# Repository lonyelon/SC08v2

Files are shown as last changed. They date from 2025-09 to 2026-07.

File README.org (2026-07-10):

#+title: SC08v2: Simple Computer (8-bits, version 2)

The SC08v2 is a super-simple, *open-hardware 8bit computer* built for retro hardware enthusiasts,
for which a custom default **microcode**, *ISA*, *assembler*, *programming language (based on LISP)*, *compiler* and *operating system* are included.
The design is modular, so any of that can be replaced at any time by the user:

#+BEGIN_EXPORT html
<p align="center">
  <img src="doc/stack.svg" width="500px"/>
</p>
#+END_EXPORT

This repository contains various directories and files that help design, build and test both the computer's hardware and it's software. Those files and directories are the following:

| Directory    | Explanation                                                                             |
|--------------+-----------------------------------------------------------------------------------------|
| =assembler/= | Converts assembly code to binary data.                                                  |
| =microcode/= | Files and scripts that help with designing and building the microcode for the computer. |
| =simulator/= | A complete simulator to test software in.                                               |
| =code/=      | Software for the CPU.                                                                   |
| =code/so=    | Complete OS.                                                                            |
| =doc/=       | Documentation.                                                                          |
| =kicad/=     | KiCAD hardware designs.                                                                 |
| =drawio/=    | DrawIO diagrams.                                                                        |

* Developing software

Check the [[doc/programmers-manual.md][programmers manual]] for a detailed guide on how to make software for the CPU.

* Running software in the CPU

To run software in the *simulated* CPU one has two follow two steps: compilation and execution. Let's run one of the test programs for example:

1. Compile the program by running the compiler: ~python3 ./comp/compiler.py ./asm/test-programs/mult.asm~.
   This will result in a file named =result.bin= being created, which can be either flashed into the CPU's ROM or executed by the simulator.
   Note that the file has a size of exactly 64KB.
2. Run the simulator by entering the =sim= directory and then executing ~cargo run ../result.bin | grep -E '^[0-9]+'~.
   In this case, enter a number (smaller than 255) and press enter.
   Repeat that step and the product of both will be outputted.

This shows that the simulator needs machine code and can not work with assembly code, since it is a one-to-one digital recreation of the real CPU.

* Contributing

Anything can be added to this repo, in whatever programming language you choose to make it, as long as it is a tool or some documentation for the SC08v2.

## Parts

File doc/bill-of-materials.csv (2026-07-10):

Material | Count | Price per unit | Total | Link
6116 | 1
28C64 | 0 | 0
28C512 | 0 | 0
74HC00 | 0 | 0
74HC85 | 0 | 0
74HC86 | 0 | 0
74HC151 | 0 | 0
74HC161 | 3 | 0
74HC245 | 1 | 0
74HC273 | 5 | 0
74HC283 | 0 | 0
100nF C | 9
12uF C | 4
USB poweronly | 1
5.1k Resistor | 1
1nF >=50V C | 1

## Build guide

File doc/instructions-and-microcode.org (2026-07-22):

#+title: SC08v2 default instruction set

The SC08v2 has quite a weird set of instructions by default.
First, we have the [[instructions]] themselves, which tell the CPU what to do.
[[Instruction modifiers]] tell it from where to get the data (or where to store it) after the instruction executed.

For example, ~ADD.num 0x60~ is the function ~ADD~ followed by the modifier ~num~.
It means "add to whatever is on the LDA registry the number =0x60=".

* Intrucctions

The table below explains what every instruction in the CPU does.
Every byte value not in the list is assumed to do nothing, the same as ~NOI.noa~.

|-------+--------------+-------------------------------------------------|
| Name  | Byte         | Value                                           |
|-------+--------------+-------------------------------------------------|
| =NOI= | =00 000 mmm= |                                                 |
| =NAN= | =00 001 mmm= | Bitwise NAND operation between =DTA= and =DTB=. |
| =ADD= | =00 010 mmm= | Add =DTA= and =DTB=.                            |
| =SUB= | =00 011 mmm= | Substract =DTB= from =DTA=.                     |
| =SHL= | =00 100 mmm= | Shift =DTA= left.                               |
| =SHR= | =00 101 mmm= | Shift =DTA= right.                              |
| =EQU= | =00 110 mmm= | Check if =DTA= = =DTB=.                         |
| =GRE= | =00 111 mmm= | Check if =DTA= > =DTB=.                         |
| =LDD= | =01 000 mmm= | Load data into the =DTA= registry.              |
| =STD= | =10 000 mmm= | Store data from the =DTA= registry.             |
| =JUM= | =11 000 mmm= | Conditional jumps. Only jumps if ~DTA != 0xFF~. |
|-------+--------------+-------------------------------------------------|

As we can see, every instruction has two bits for the ID, three for the ALU operation (has to be =000= in non-ALU instructions to allow reading from =DTA=), and three for the modifier.

* Instruction modifiers

|--------------------+--------+---------------------------------------------------------------------------|
| Name [extra bytes] | m-bits | Description                                                               |
|--------------------+--------+---------------------------------------------------------------------------|
| =noa=              |    000 | Do nothing/Pass the value of =DTA=. On ~LDD~ it loads the value of =IFL=. |
| =num #1 [#2]=      |    001 | Hardcoded byte (could be 2 bytes for ROM operations like ~JUM~).          |
| =ram #1=           |    010 | RAM at =#1=.                                                              |
| =rom #1 #2=        |    011 | ROM at =#1 #2=.                                                           |
| =prr=              |    100 | RAM at =RAM[DTA]= (pointer)                                               |
| =ptr #1=           |    101 | RAM at =RAM[#1]= (pointer)                                                |
| =aux=              |    110 | Manage the =AUX= registry.                                                |
| =ios=              |    111 | I/O registries.                                                           |
|--------------------+--------+---------------------------------------------------------------------------|

* Valid instruction-modifier combinations

|-----------------+--------------------------------------------------------------------------------|
| Instruction     | Action                                                                         |
|-----------------+--------------------------------------------------------------------------------|
| ~ALU.noa~       | DTA = DTA                                                                      |
| ~ALU.num #1~    | DTA = DTA <> #1                                                                |
| ~ALU.ram #1~    | DTA = DTA <> RAM[#1]                                                           |
| ~ALU.rom #1 #2~ | DTA = DTA <> ROM[#1][#2]                                                       |
| ~ALU.prr~       | DTA = DTA <> RAM[DTA]                                                          |
| ~ALU.ptr #1~    | DTA = DTA <> RAM[#1]                                                           |
| ~ALU.ios~       | DTA = DTA <> INP                                                               |
|-----------------+--------------------------------------------------------------------------------|
| ~LDD.noa~       | DTA = IFL                                                                      |
| ~LDD.num #1~    | DTA = #1                                                                       |
| ~LDD.ram #1~    | DTA = RAM[#1]                                                                  |
| ~LDD.rom #1 #2~ | DTA = ROM[#1][#2]                                                              |
| ~LDD.prr~       | DTA = RAM[DTA]                                                                 |
| ~LDD.ptr #1~    | DTA = RAM[#1]                                                                  |
| ~LDD.ios~       | DTA = INP                                                                      |
|-----------------+--------------------------------------------------------------------------------|
| ~STD.noa~       | Also called NOI.noa. Do nothing.                                               |
| ~STD.num~       | NOI.noa.                                                                       |
| ~STD.ram #1~    | RAM[#1] = DTA                                                                  |
| ~STD.rom #1 #2~ | ROM[#1][#2] = DTA                                                              |
| ~STD.prr~       | RAM[DTA] = DTA                                                                 |
| ~STD.ptr #1~    | RAM[#1] = DTA                                                                  |
| ~STD.ios~       | OUT = DTA                                                                      |
|-----------------+--------------------------------------------------------------------------------|
| ~JUM.noa~       | Also called NOI.noa. Do nothing.                                               |
| ~JUM.noa~       | PC = #1 #2                                                                     |
| ~JUM.ram #1 #2~ | PC = RAM[#1] RAM[#2]                                                           |
| ~JUM.rom~       | NOI.noa? Only valid if ROM has 2 address bytes, PC S forces SWT and max(PC)=15 |
| ~JUM.prr #1~    | NOI.noa? PC = RAM[DTA] RAM[#1]                                                 |
| ~JUM.ptr #1 #2~ | NOI.noa? PC = RAM[#1] RAM[#2]                                                  |
| ~JUM.ios #1~    | NOI.noa? PC = INP #1                                                           |
|-----------------+--------------------------------------------------------------------------------|

* Full microcode

The full microcode with explanations on what it does can be found under [[../microcode]].

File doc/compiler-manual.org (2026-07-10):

#+title: How does the compiler work

The compiler adds another layer of abstraction on top of the assembler, allowing for the use of a LISP-like programming language (=sclsp=) instead of the assembly language.

The compiler evaluates every expression bottom-up, meaning that, in code like:

#+BEGIN_SRC lsp
(if (> a b) (- a (+ 3 2)))
#+END_SRC

The first element to get evaluated is ~(+ 3 2)~.

Different expressions have different rules.
For example, an `if` expression like ~(if X Y)~ gets translated to:

#+BEGIN_SRC asm
        X               ;; Run X first
        EQU.num 0x00    ;; Invert the value
        JUM.num :endif  ;; Jump if X condition was not met (thats why the value was inverted)
        Y               ;; Execute Y if X was met
:endif  NOI.noa         ;; Placeholder instruction to ensure a destination point for the jump
#+END_SRC

* Common instructions

#+BEGIN_SRC asm
; (= V0 V1)
        LDD.ram V0
        EQU.ram V1

; (= N0 N1)
        LDD.num N0
        EQU.num N1

; (= EXPR0 V1)
        EXPR0
        EQU.ram V1

; (= V0 EXPR0) same as (= EXPR0 V1).
; (> * *) same as (= * *), replace EQU with GRE.
; (<= * *) run (> * *), then
        XOR.num 0xff
; (>= * *)
; (< * *)

; (if N0 EXPR1)
        LDD.num N0
        JUM.num :ifblk
        LDD.num 0xff
        JUM.num :endif
:ifblk  EXPR1
:endif  ...
; (if V0 EXPR1)
        LDD.ram V0
        JUM.num :ifblk
        LDD.num 0xff
        JUM.num :endif
:ifblk  EXPR1
:endif  ...
; (if EXPR0 EXPR1)
        EXPR0
        JUM.num :ifblk
        LDD.num 0xff
        JUM.num :endif
:ifblk  EXPR1
:endif  ...
    
; (if N0 N1 N2)
; (if N0 V1 N2)
; (if N0 EXPR1 N2)
; (if V0 N1 N2)
; (if V0 V1 N2)
; (if V0 EXPR1 N2)
; (if EXPR0 N1 N2)
; (if EXPR0 V1 N2)
; (if EXPR0 EXPR1 N2)
    
; (if N0 N1 V2)
; (if N0 V1 V2)
; (if N0 EXPR1 V2)
; (if V0 N1 V2)
; (if V0 V1 V2)
; (if V0 EXPR1 V2)
; (if EXPR0 N1 V2)
; (if EXPR0 V1 V2)
; (if EXPR0 EXPR1 V2)
    
; (if N0 N1 EXPR2)
; (if N0 V1 EXPR2)
; (if N0 EXPR1 EXPR2)
; (if V0 N1 EXPR2)
; (if V0 V1 EXPR2)
; (if V0 EXPR1 EXPR2)
; (if EXPR0 N1 EXPR2)
; (if EXPR0 V1 EXPR2)
; (if EXPR0 EXPR1 EXPR2)
        EXPR0
        JUM.num :ifblk
        EXPR2
        LDD.num 0xff
        JUM.num :endif
:ifblk  EXPR1
:endif  ...

; (= V0 N1)
        LDD.num N1
        STD.ram V0
; (= V0 V1)
        LDD.ram V0
        ADD.ram V1
        STD.ram V0
; (= V0 EXPR1)
        EXPR1
        ADD.ram V0
        STD.ram V0
    
; (+ V0 N1)
        LDD.num N1
        ADD.ram V0
; (+ V0 V1)
        LDD.ram V1
        ADD.ram V0
; (+ V0 EXPR1)
        EXPR1
        ADD.ram V0
    
; (- V0 N1)
        LDD.num N1
        SUB.ram V0
; (- V0 V1)
        LDD.ram V1
        SUB.ram V0
; (- V0 EXPR1)
        EXPR1
        SUB.ram V0
#+END_SRC

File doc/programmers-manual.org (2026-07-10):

#+title: Assembly programmer's manual

This is the manual for making software for the SC08v2.

* The basics

We use the assembler located at `comp/assembler.py` to convert assembly code into a ROM binary file. The assembly code we use is a custom one made with simplicity in mind, so it should not be really hard to get used to it.

The instructions in the assembly language are made of two elements, the instruction itself and the modifier. For example `LDD.inp` means "load data into the data registry from the input", while `LDD.ram 0x00` means "load data into the data registry from ram at position 0x00". As you can see, arguments need to be passed to instructions sometimes, like the `0x00` before. We will explore the most important instructions and modifiers later, so don't worry too much about this.

To run your software, stored in a `result.bin` file generated after assembling, we can use the program located in `sim/`, which is a full simulator of the CPU written in rust. To run it, use `cargo run <file>`, where the file is out `result.bin`.

* Our first program

Let's build a really basic program for the CPU. In this case, we want to get a number from the user, add one to it and then print it. That program is four bytes in size, and looks like this:

#+BEGIN_SRC asm
        LDD.inp   ; Load the value from the input registry into the RA registry.
        ADD.num 1 ; Add 1 to the RA registry, store it back to RA.
        STD.out   ; Store the value of the RA registry in the output registry.
#+END_SRC

We will ignore the tabs at the beginning of each line for now, we will revisit them later when looking into the `JUM` instruction.

Now, let's make a more complicated program. In this case, we want the user to give two numbers and then add them together. Since we now need two numbers, and we only have one data registry, we need to store the first number to ram to prevent the second one from overwriting it. Then, we add the second number, the one we already have in the data registry, with the first one, placed in the ram at position 0 (0x00).

#+BEGIN_SRC asm
        LDD.inp      ; Get input into RA.
        STD.ram 0x00 ; Store RA into RAM at 0x00.
        LDD.inp      ; Get another input into RA, overwriting the previous one.
        ADD.ram 0x00 ; Add to it the value in RAM at 0x00 (the first input we got).
        STD.out      ; Output the result.
#+END_SRC

Manually managing RAM positions can be a pain, so the assembler allows us to assign names to RAM positions so that we don't lose track of them:

#+BEGIN_SRC asm
#var    first   0x00 ; first = RAM[0x00]
        LDD.inp
        STD.ram first
        LDD.inp
        ADD.ram first
        STD.out
#+END_SRC

And, as we can see, the result is much cleaner. 

** Comments and blank lines

Comments can be added at any place of the program to explain what the software is doing. The following code is the program we already made, but commented so that someone reading it knows what we are doing:

#+BEGIN_SRC asm
#var    first   0x00

        ;; Get the first number.
        LDD.inp
        STD.ram first ; See? we can do this too!
        
        ;; Get the second number.
        LDD.inp
        
        ;; Add them and show the result.
        ADD.ram first
        STD.out

;; Comments can go here too btw, it really doesn't matter.
#+END_SRC

Blank lines can also be really helpful to make the code more readable, so use them freely :).

** The JUM instruction

Another very important instruction is the JUM instruction.
This one allows jumping (surprise?) to a position in ROM.
But things aren't that easy.
The ~JUM~ instruction ONLY jumps if the data registry has a value different than =0=.
So if we want to jump unconditionally, we must run something like:

#+BEGIN_SRC asm
        LDD.num 0xFF   ; Required for the jump to take place. Could be any
                       ; number other than 0.
        JUM.num 0x1234 ; Take note of this.
#+END_SRC

Isn't that =0x1234= weird? This is an 8 bit CPU, but that number is 16 bits in size!
That's because ROM addresses are 16 bits in size to allow 64 KB of storage.
Since the bus (or anything in the CPU, really) can't handle more than 8 bits of data at a given time, the number is split into two and read sequentially.
That results on the ROM looking something like this:

#+BEGIN_SRC asm
0x0003 JUM.num
0x0004 0x12
0x0005 0x34
#+END_SRC

Let's use the JUM instruction to make an infinite loop:

#+BEGIN_SRC asm
        LDD.num 0xFF
        JUM.num 0x0003
#+END_SRC

This is some really awful code, mainly because it is impossible to look at it and know what it is doing.
We see that it is loading 0xff to the data registry (so we can jump) and then jumping to ROM 0x0003.
What is that rom position?
We may not know, and that is why it is awful.
If we count the rom positions, we see that the 0th one is reserved (we won't explain why now),
the first one is used for the ~LDD.num~ instruction, the second one for the number to be loaded (=0xff=), the third one for the jump instruction, the... Eureka!
We are jumping to the third position in the ROM, which is the ~JUM.num~ instruction, so this is an infinite loop that jumps to itself!

See how hard reading that code is?
That's why the assembler allows for naming the positions in the ROM, because in more complicated programs, counting manually to the position we want to jump is impossible, and that position may change in the future if we add instruction in between.
Using position names, the program just becomes:

#+BEGIN_SRC asm
        LDO.num 0xff
:halt   JUM.num :halt
#+END_SRC

Which we can easily understand.
This is the reason we have to always include tabs or spaces before the instructions, in case we want to tag them.

** Comparisons

~JUM~ instructions only become useful once comparisons are understood.
The CPU includes two kinds of comparisons, equality (~EQU~) and greater (~GRE~), but combining both we can get all others.

The comparison instructions take whatever is in the data registry, compare it to a value we give them, and then store the result back into the data registry.
If the comparison was successful, =DTA= is set to =0xFF=, if not, =0x00=.
For example, the following program asks the user for a number, and if the number is 33, then it jumps to another place in the code if it is:

#+BEGIN_SRC asm
        LDD.inp
        EQU.num 33         ; Is the number equal to 33?
        JUM.num :somewhere ; If true, jump to :somewhere
        ...                ; If not, continue here.
#+END_SRC

Let's see what is happening here...
First, the user is being asked for a number, which is getting stored in the data registry.
Then, the number is compared to 33, and if it is equal, =0xff= is written to the data registry and so the ~JUM~ instruction is executed.
If the number is not 33, then =0x00= is stored into the dta registry and the jump instruction is passed.

So that is great, we can do a `== 33` comparison and a `> 33` one, but how about something like `<= 33`? For that one, we need to combine the previous two:

#+BEGIN_SRC asm
        ;; Get the number from the user and store it.
        LDD.inp
        STD.ram 0x00
        
        ;; Check if it is 33, if it is, jump to "true".
        EQU.num 33
        JUM.num :true
        
        ;; Check if the number is greater than 33, if it is, jump to "false".
        LDD.ram 0x00
        GRE.num 33
        JUM.num :false
        
        ;; This gets executed if the first jump executed or if the last one
        ;; didn't.
:true   LDD.num 1
        STD.out
        LDD.num 0xff
        JUM.num :halt

        ;; This gets executed if the first jump didn't get executed but the last
        ;; one did.
:false  LDD.num 0
        STD.out
        LDD.num 0xff
        JUM.num :halt
        
:halt   JUM.num :halt
#+END_SRC

As always, writing this is a pain, but in this case there is no solution for it. Work is being done in a macro system to define a new instruction like `LES.num 33` that gets transformed into the code above at compile-time, but this won't be available soon.

** Pointers

Pointers are a hard-to-understand tool, but a really powerfull one. We will assume going forward the the reader is familiar with how pointers work.

Sometimes the value we have in the data registry is not intended to be a value by itself, but a pointer to a position in ram. For example, in the following program we see how we can access the 16th position in ram by loading the number into the data registry and then resolving the pointer:

#+BEGIN_SRC asm
        LDD.num 0x10 ;; Load 16 into DTA.
        LDD.ptr      ;; Load the 16th position in ram to DTA.
#+END_SRC

Maybe the value we load is by itself a pointer to another place, which can be resolved with ease again:

#+BEGIN_SRC asm
        LDD.num 0x10 ;; Load 16 into DTA.
        LDD.prr      ;; Load the 16th position in ram to DTA.
        LDD.prr      ;; Load the XXth position in ram to DTA.
#+END_SRC

To save instructions, instead of loading data into DTA, we may just use the `prr` (pointer-to-ram) modifier. The following program does the same as the above one, but it saves one instruction:

#+BEGIN_SRC asm
        LDD.prr 0x10 ;; Load RAM at position 0x10, use that as a pointer and resolve it.
        LDD.ptr      ;; Same as before.
#+END_SRC

We could be confused on why to use `ptr` when `prr` exists, but there are cases where it's needed. The one above is one good example of it, but many others can be shown. The next program would be more complicated if we only used `prr` and not `ptr`:

#+BEGIN_SRC asm
        LDD.ram 0x00
        ADD.num 2
        LDD.ptr
        STD.out
#+END_SRC

For a last example, the next program print all the contents in the RAM except for the first position, used for the counter. We leave the explanation as homework for the reader.

#+BEGIN_SRC asm
#var    counter 0x00

        ;; Load and increment the counter.
start   LDD.ram counter
        ADD.num 1
        STD.ram counter
        
        ;; Did we loop back to 0x00? if so, halt.
        EQU.num 0x00
        JUM.num :halt
        
        ;; Show the value in that ram position
        LDD.ptr counter
        STD.out
        
        ;; Go back to the start
        LDD.num 0xff
        JUM.num start
        
        ;; Halt.
halt    JUM.num :halt
#+END_SRC

** Includes

Files can be included into other files, like in C:

#+BEGIN_SRC asm
#inc    firstinclude.asm
#inc    secondinclude.asm
#+END_SRC

Beware of include loops! The assembler doen't check for them yet!

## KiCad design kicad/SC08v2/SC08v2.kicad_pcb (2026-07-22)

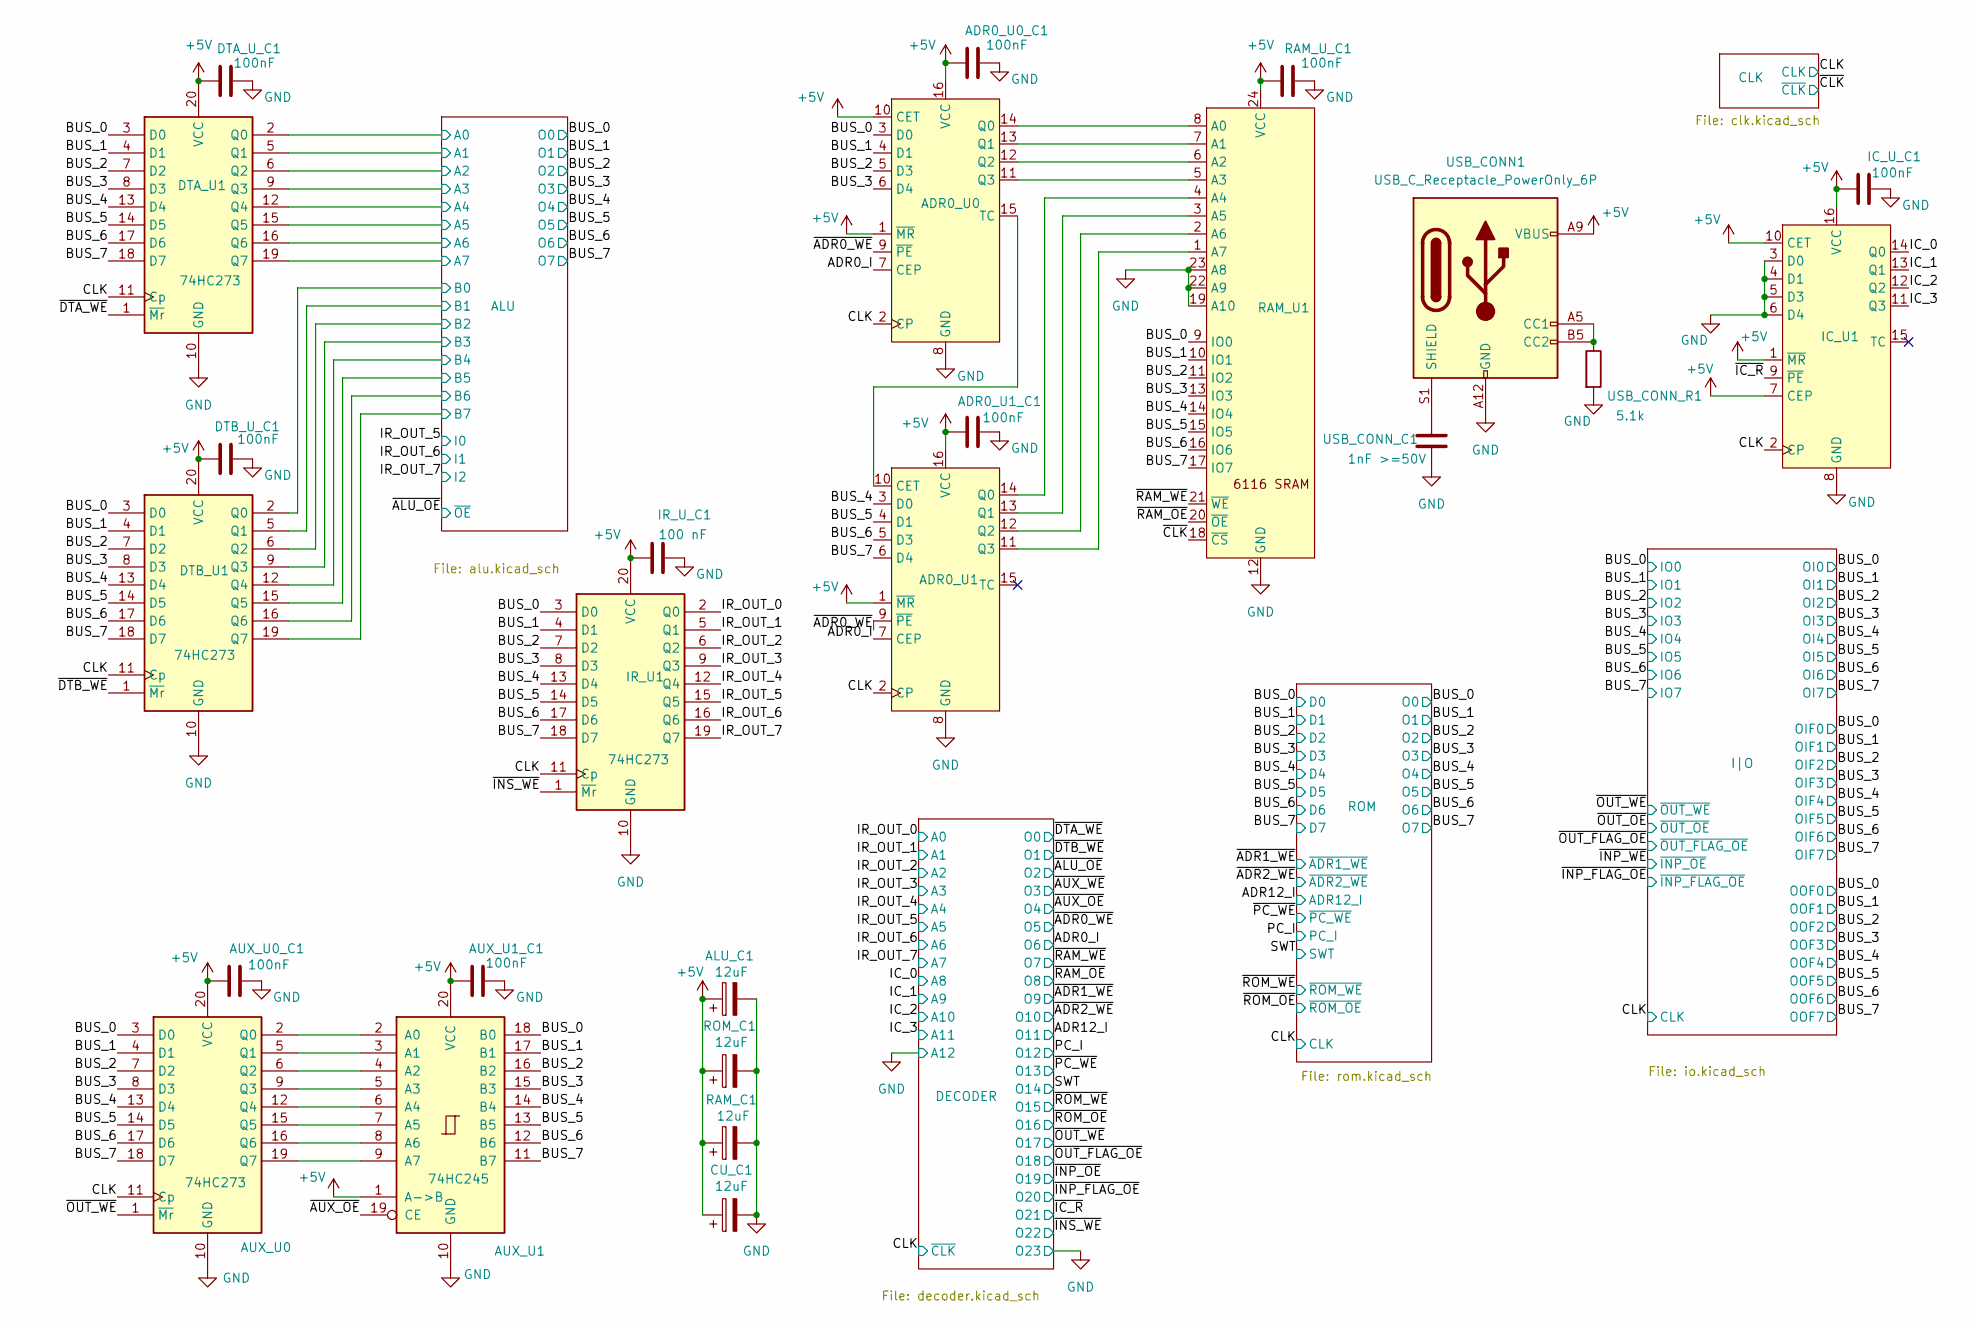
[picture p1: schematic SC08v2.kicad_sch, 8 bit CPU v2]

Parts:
ADR0_U0, ADR0_U1: DIP-16_W7.62mm
ADR0_U0_C1, ADR0_U1_C1: 100nF; C_Disc_D3.0mm_W1.6mm_P2.50mm
ALU_C1: 12uF; C_Radial_D5.0mm_H5.0mm_P2.00mm
AUX_U0: 74HC273; DIP-20_W7.62mm
AUX_U0_C1, AUX_U1_C1: 100nF; C_Disc_D3.0mm_W1.6mm_P2.50mm
AUX_U1: 74HC245; DIP-20_W7.62mm
CU_C1: 12uF; C_Radial_D5.0mm_H5.0mm_P2.00mm
DTA_U1: 74HC273; DIP-20_W7.62mm
DTA_U_C1: 100nF; C_Disc_D3.0mm_W1.6mm_P2.50mm
DTB_U1: 74HC273; DIP-20_W7.62mm
DTB_U_C1: 100nF; C_Disc_D3.0mm_W1.6mm_P2.50mm
IC_U1: DIP-16_W7.62mm
IC_U_C1: 100nF; C_Disc_D3.0mm_W1.6mm_P2.50mm
IR_U1: 74HC273; DIP-20_W7.62mm
IR_U_C1: 100 nF; C_Disc_D3.0mm_W1.6mm_P2.50mm
RAM_C1: 12uF; C_Radial_D5.0mm_H5.0mm_P2.00mm
RAM_U1: DIP-24_18.0mmx34.29mm_W15.24mm
RAM_U_C1: 100nF; C_Disc_D3.0mm_W1.6mm_P2.50mm
ROM_C1: 12uF; C_Radial_D5.0mm_H5.0mm_P2.00mm
USB_CONN1: USB_C_Receptacle_PowerOnly_6P; USB_C_Receptacle_GCT_USB4125-xx-x-0190_6P_TopMnt_Horizontal
USB_CONN_C1: 1nF >=50V; C_Disc_D3.0mm_W1.6mm_P2.50mm
USB_CONN_R1: 5.1k; R_Axial_DIN0204_L3.6mm_D1.6mm_P5.08mm_Horizontal

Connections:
+5V: ADR0_U0.1 (~MR), ADR0_U0.10 (CET), ADR0_U0.16 (VCC), ADR0_U0_C1.1, ADR0_U1.1 (~MR), ADR0_U1.16 (VCC), ADR0_U1_C1.1, ALU_C1.1, AUX_U0.20 (VCC), AUX_U0_C1.1, AUX_U1.1 (A->B), AUX_U1.20 (VCC), AUX_U1_C1.1, CU_C1.1, DTA_U1.20 (VCC), DTA_U_C1.1, DTB_U1.20 (VCC), DTB_U_C1.1, IC_U1.1 (~MR), IC_U1.7 (CEP), IC_U1.10 (CET), IC_U1.16 (VCC), IC_U_C1.1, IR_U1.20 (VCC), IR_U_C1.1, RAM_C1.1, RAM_U1.24 (VCC), RAM_U_C1.1, ROM_C1.1, USB_CONN1.A9 (VBUS), USB_CONN1.B9 (VBUS); also elsewhere on the board
/ADR0_I: ADR0_U0.7 (CEP), ADR0_U1.7 (CEP); also elsewhere on the board
/ALU/A0: DTA_U1.2 (Q0); also elsewhere on the board
/ALU/A1: DTA_U1.5 (Q1); also elsewhere on the board
/ALU/A2: DTA_U1.6 (Q2); also elsewhere on the board
/ALU/A3: DTA_U1.9 (Q3); also elsewhere on the board
/ALU/A4: DTA_U1.12 (Q4); also elsewhere on the board
/ALU/A5: DTA_U1.15 (Q5); also elsewhere on the board
/ALU/A6: DTA_U1.16 (Q6); also elsewhere on the board
/ALU/A7: DTA_U1.19 (Q7); also elsewhere on the board
/ALU/B0: DTB_U1.2 (Q0); also elsewhere on the board
/ALU/B1: DTB_U1.5 (Q1); also elsewhere on the board
/ALU/B2: DTB_U1.6 (Q2); also elsewhere on the board
/ALU/B3: DTB_U1.9 (Q3); also elsewhere on the board
/ALU/B4: DTB_U1.12 (Q4); also elsewhere on the board
/ALU/B5: DTB_U1.15 (Q5); also elsewhere on the board
/ALU/B6: DTB_U1.16 (Q6); also elsewhere on the board
/ALU/B7: DTB_U1.19 (Q7); also elsewhere on the board
/BUS_0: ADR0_U0.3 (D0), AUX_U0.3 (D0), AUX_U1.18 (B0), DTA_U1.3 (D0), DTB_U1.3 (D0), IR_U1.3 (D0), RAM_U1.9 (IO0); also elsewhere on the board
/BUS_1: ADR0_U0.4 (D1), AUX_U0.4 (D1), AUX_U1.17 (B1), DTA_U1.4 (D1), DTB_U1.4 (D1), IR_U1.4 (D1), RAM_U1.10 (IO1); also elsewhere on the board
/BUS_2: ADR0_U0.5 (D3), AUX_U0.7 (D2), AUX_U1.16 (B2), DTA_U1.7 (D2), DTB_U1.7 (D2), IR_U1.7 (D2), RAM_U1.11 (IO2); also elsewhere on the board
/BUS_3: ADR0_U0.6 (D4), AUX_U0.8 (D3), AUX_U1.15 (B3), DTA_U1.8 (D3), DTB_U1.8 (D3), IR_U1.8 (D3), RAM_U1.13 (IO3); also elsewhere on the board
/BUS_4: ADR0_U1.3 (D0), AUX_U0.13 (D4), AUX_U1.14 (B4), DTA_U1.13 (D4), DTB_U1.13 (D4), IR_U1.13 (D4), RAM_U1.14 (IO4); also elsewhere on the board
/BUS_5: ADR0_U1.4 (D1), AUX_U0.14 (D5), AUX_U1.13 (B5), DTA_U1.14 (D5), DTB_U1.14 (D5), IR_U1.14 (D5), RAM_U1.15 (IO5); also elsewhere on the board
/BUS_6: ADR0_U1.5 (D3), AUX_U0.17 (D6), AUX_U1.12 (B6), DTA_U1.17 (D6), DTB_U1.17 (D6), IR_U1.17 (D6), RAM_U1.16 (IO6); also elsewhere on the board
/BUS_7: ADR0_U1.6 (D4), AUX_U0.18 (D7), AUX_U1.11 (B7), DTA_U1.18 (D7), DTB_U1.18 (D7), IR_U1.18 (D7), RAM_U1.17 (IO7); also elsewhere on the board
/CLK: ADR0_U0.2 (CP), ADR0_U1.2 (CP), AUX_U0.11 (Cp), DTA_U1.11 (Cp), DTB_U1.11 (Cp), IC_U1.2 (CP), IR_U1.11 (Cp); also elsewhere on the board
/IC_0: IC_U1.14 (Q0); also elsewhere on the board
/IC_1: IC_U1.13 (Q1); also elsewhere on the board
/IC_2: IC_U1.12 (Q2); also elsewhere on the board
/IC_3: IC_U1.11 (Q3); also elsewhere on the board
/IR_OUT_0: IR_U1.2 (Q0); also elsewhere on the board
/IR_OUT_1: IR_U1.5 (Q1); also elsewhere on the board
/IR_OUT_2: IR_U1.6 (Q2); also elsewhere on the board
/IR_OUT_3: IR_U1.9 (Q3); also elsewhere on the board
/IR_OUT_4: IR_U1.12 (Q4); also elsewhere on the board
/IR_OUT_5: IR_U1.15 (Q5); also elsewhere on the board
/IR_OUT_6: IR_U1.16 (Q6); also elsewhere on the board
/IR_OUT_7: IR_U1.19 (Q7); also elsewhere on the board
/~ADR0_WE: ADR0_U0.9 (~PE), ADR0_U1.9 (~PE); also elsewhere on the board
/~AUX_OE: AUX_U1.19 (CE); also elsewhere on the board
/~CLK: RAM_U1.18 (~CS); also elsewhere on the board
/~DTA_WE: DTA_U1.1 (~Mr); also elsewhere on the board
/~DTB_WE: DTB_U1.1 (~Mr); also elsewhere on the board
/~IC_R: IC_U1.9 (~PE); also elsewhere on the board
/~INS_WE: IR_U1.1 (~Mr); also elsewhere on the board
/~OUT_WE: AUX_U0.1 (~Mr); also elsewhere on the board
/~RAM_OE: RAM_U1.20 (~OE); also elsewhere on the board
/~RAM_WE: RAM_U1.21 (~WE); also elsewhere on the board
GND: ADR0_U0.8 (GND), ADR0_U0_C1.2, ADR0_U1.8 (GND), ADR0_U1_C1.2, ALU_C1.2, AUX_U0.10 (GND), AUX_U0_C1.2, AUX_U1.10 (GND), AUX_U1_C1.2, CU_C1.2, DTA_U1.10 (GND), DTA_U_C1.2, DTB_U1.10 (GND), DTB_U_C1.2, IC_U1.3 (D0), IC_U1.4 (D1), IC_U1.5 (D3), IC_U1.6 (D4), IC_U1.8 (GND), IC_U_C1.2, IR_U1.10 (GND), IR_U_C1.2, RAM_C1.2, RAM_U1.12 (GND), RAM_U1.19 (A10), RAM_U1.22 (A9), RAM_U1.23 (A8), RAM_U_C1.2, ROM_C1.2, USB_CONN1.A12 (GND), USB_CONN1.B12 (GND), USB_CONN_C1.2, USB_CONN_R1.2; also elsewhere on the board
unnamed: ADR0_U0.14 (Q0), RAM_U1.8 (A0)
unnamed: ADR0_U0.13 (Q1), RAM_U1.7 (A1)
unnamed: ADR0_U0.12 (Q2), RAM_U1.6 (A2)
unnamed: ADR0_U0.11 (Q3), RAM_U1.5 (A3)
unnamed: ADR0_U0.15 (TC), ADR0_U1.10 (CET)
unnamed: ADR0_U1.14 (Q0), RAM_U1.4 (A4)
unnamed: ADR0_U1.13 (Q1), RAM_U1.3 (A5)
unnamed: ADR0_U1.12 (Q2), RAM_U1.2 (A6)
unnamed: ADR0_U1.11 (Q3), RAM_U1.1 (A7)
unnamed: AUX_U0.2 (Q0), AUX_U1.2 (A0)
unnamed: AUX_U0.5 (Q1), AUX_U1.3 (A1)
unnamed: AUX_U0.6 (Q2), AUX_U1.4 (A2)
unnamed: AUX_U0.9 (Q3), AUX_U1.5 (A3)
unnamed: AUX_U0.12 (Q4), AUX_U1.6 (A4)
unnamed: AUX_U0.15 (Q5), AUX_U1.7 (A5)
unnamed: AUX_U0.16 (Q6), AUX_U1.8 (A6)
unnamed: AUX_U0.19 (Q7), AUX_U1.9 (A7)
unnamed: USB_CONN1.A5 (CC1), USB_CONN1.B5 (CC2), USB_CONN_R1.1
unnamed: USB_CONN1.S1 (SHIELD), USB_CONN_C1.1

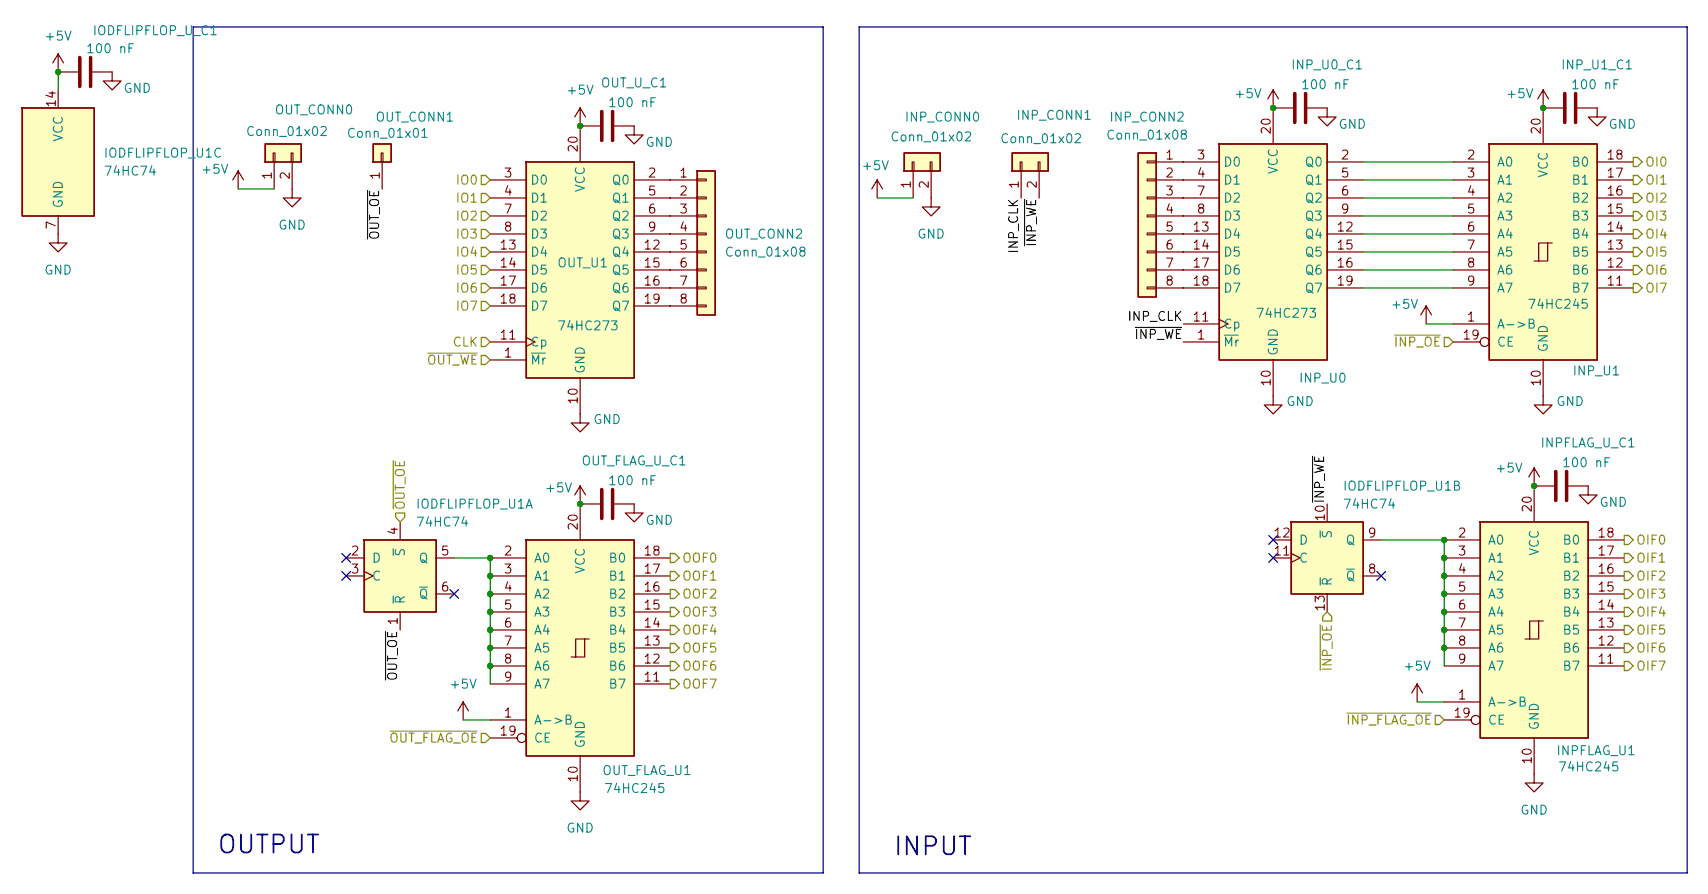
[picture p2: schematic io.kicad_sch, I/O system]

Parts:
INPFLAG_U1: 74HC245; DIP-20_W7.62mm
INPFLAG_U_C1: 100 nF; C_Disc_D3.0mm_W1.6mm_P2.50mm
INP_CONN0, INP_CONN1: Conn_01x02; PinHeader_1x02_P2.54mm_Vertical
INP_CONN2: Conn_01x08; PinHeader_1x08_P2.54mm_Vertical
INP_U0: 74HC273; DIP-20_W7.62mm
INP_U0_C1, INP_U1_C1: 100 nF; C_Disc_D3.0mm_W1.6mm_P2.50mm
INP_U1: 74HC245; DIP-20_W7.62mm
IODFLIPFLOP_U1: 74HC74; DIP-14_W7.62mm
IODFLIPFLOP_U_C1: 100 nF; C_Disc_D3.0mm_W1.6mm_P2.50mm
OUT_CONN0: Conn_01x02; PinHeader_1x02_P2.54mm_Vertical
OUT_CONN1: Conn_01x01; PinHeader_1x01_P2.54mm_Vertical
OUT_CONN2: Conn_01x08; PinHeader_1x08_P2.54mm_Vertical
OUT_FLAG_U1: 74HC245; DIP-20_W7.62mm
OUT_FLAG_U_C1: 100 nF; C_Disc_D3.0mm_W1.6mm_P2.50mm
OUT_U1: 74HC273; DIP-20_W7.62mm
OUT_U_C1: 100 nF; C_Disc_D3.0mm_W1.6mm_P2.50mm

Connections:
+5V: INPFLAG_U1.1 (A->B), INPFLAG_U1.20 (VCC), INPFLAG_U_C1.1, INP_CONN0.1, INP_U0.20 (VCC), INP_U0_C1.1, INP_U1.1 (A->B), INP_U1.20 (VCC), INP_U1_C1.1, IODFLIPFLOP_U1.14 (VCC), IODFLIPFLOP_U_C1.1, OUT_CONN0.1, OUT_FLAG_U1.1 (A->B), OUT_FLAG_U1.20 (VCC), OUT_FLAG_U_C1.1, OUT_U1.20 (VCC), OUT_U_C1.1; also elsewhere on the board
/BUS_0: INPFLAG_U1.18 (B0), INP_U1.18 (B0), OUT_FLAG_U1.18 (B0), OUT_U1.3 (D0); also elsewhere on the board
/BUS_1: INPFLAG_U1.17 (B1), INP_U1.17 (B1), OUT_FLAG_U1.17 (B1), OUT_U1.4 (D1); also elsewhere on the board
/BUS_2: INPFLAG_U1.16 (B2), INP_U1.16 (B2), OUT_FLAG_U1.16 (B2), OUT_U1.7 (D2); also elsewhere on the board
/BUS_3: INPFLAG_U1.15 (B3), INP_U1.15 (B3), OUT_FLAG_U1.15 (B3), OUT_U1.8 (D3); also elsewhere on the board
/BUS_4: INPFLAG_U1.14 (B4), INP_U1.14 (B4), OUT_FLAG_U1.14 (B4), OUT_U1.13 (D4); also elsewhere on the board
/BUS_5: INPFLAG_U1.13 (B5), INP_U1.13 (B5), OUT_FLAG_U1.13 (B5), OUT_U1.14 (D5); also elsewhere on the board
/BUS_6: INPFLAG_U1.12 (B6), INP_U1.12 (B6), OUT_FLAG_U1.12 (B6), OUT_U1.17 (D6); also elsewhere on the board
/BUS_7: INPFLAG_U1.11 (B7), INP_U1.11 (B7), OUT_FLAG_U1.11 (B7), OUT_U1.18 (D7); also elsewhere on the board
/CLK: OUT_U1.11 (Cp); also elsewhere on the board
/I|O/INP_CLK: INP_CONN1.1, INP_U0.11 (Cp)
/I|O/~INP_WE: INP_CONN1.2, INP_U0.1 (~Mr), IODFLIPFLOP_U1.10 (~S)
/~INP_FLAG_OE: INPFLAG_U1.19 (CE); also elsewhere on the board
/~INP_WE: INP_U1.19 (CE), IODFLIPFLOP_U1.13 (~R)
/~OUT_FLAG_OE: OUT_FLAG_U1.19 (CE); also elsewhere on the board
/~OUT_OE: IODFLIPFLOP_U1.1 (~R), IODFLIPFLOP_U1.4 (~S), OUT_CONN1.1 (Pin_1_1)
/~OUT_WE: OUT_U1.1 (~Mr); also elsewhere on the board
GND: INPFLAG_U1.10 (GND), INPFLAG_U_C1.2, INP_CONN0.2, INP_U0.10 (GND), INP_U0_C1.2, INP_U1.10 (GND), INP_U1_C1.2, IODFLIPFLOP_U1.7 (GND), IODFLIPFLOP_U_C1.2, OUT_CONN0.2, OUT_FLAG_U1.10 (GND), OUT_FLAG_U_C1.2, OUT_U1.10 (GND), OUT_U_C1.2; also elsewhere on the board
unnamed: INPFLAG_U1.2 (A0), INPFLAG_U1.3 (A1), INPFLAG_U1.4 (A2), INPFLAG_U1.5 (A3), INPFLAG_U1.6 (A4), INPFLAG_U1.7 (A5), INPFLAG_U1.8 (A6), INPFLAG_U1.9 (A7), IODFLIPFLOP_U1.9 (Q)
unnamed: INP_CONN2.1, INP_U0.3 (D0)
unnamed: INP_CONN2.2, INP_U0.4 (D1)
unnamed: INP_CONN2.3, INP_U0.7 (D2)
unnamed: INP_CONN2.4, INP_U0.8 (D3)
unnamed: INP_CONN2.5, INP_U0.13 (D4)
unnamed: INP_CONN2.6, INP_U0.14 (D5)
unnamed: INP_CONN2.7, INP_U0.17 (D6)
unnamed: INP_CONN2.8, INP_U0.18 (D7)
unnamed: INP_U0.2 (Q0), INP_U1.2 (A0)
unnamed: INP_U0.5 (Q1), INP_U1.3 (A1)
unnamed: INP_U0.6 (Q2), INP_U1.4 (A2)
unnamed: INP_U0.9 (Q3), INP_U1.5 (A3)
unnamed: INP_U0.12 (Q4), INP_U1.6 (A4)
unnamed: INP_U0.15 (Q5), INP_U1.7 (A5)
unnamed: INP_U0.16 (Q6), INP_U1.8 (A6)
unnamed: INP_U0.19 (Q7), INP_U1.9 (A7)
unnamed: IODFLIPFLOP_U1.5 (Q), OUT_FLAG_U1.2 (A0), OUT_FLAG_U1.3 (A1), OUT_FLAG_U1.4 (A2), OUT_FLAG_U1.5 (A3), OUT_FLAG_U1.6 (A4), OUT_FLAG_U1.7 (A5), OUT_FLAG_U1.8 (A6), OUT_FLAG_U1.9 (A7)
unnamed: OUT_CONN2.1, OUT_U1.2 (Q0)
unnamed: OUT_CONN2.2, OUT_U1.5 (Q1)
unnamed: OUT_CONN2.3, OUT_U1.6 (Q2)
unnamed: OUT_CONN2.4, OUT_U1.9 (Q3)
unnamed: OUT_CONN2.5, OUT_U1.12 (Q4)
unnamed: OUT_CONN2.6, OUT_U1.15 (Q5)
unnamed: OUT_CONN2.7, OUT_U1.16 (Q6)
unnamed: OUT_CONN2.8, OUT_U1.19 (Q7)

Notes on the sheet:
INPUT
OUTPUT

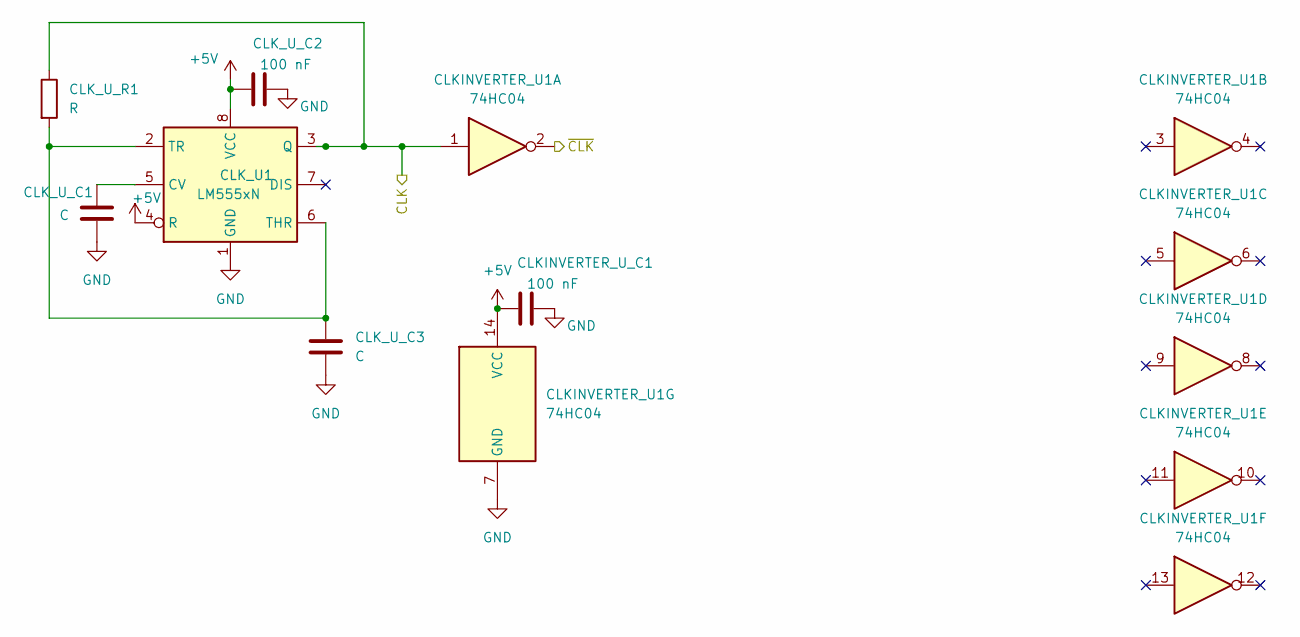
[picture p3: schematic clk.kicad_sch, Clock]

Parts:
CLKINVERTER_U1: 74HC04; DIP-14_W7.62mm
CLKINVERTER_U_C1: 100 nF; C_Disc_D3.0mm_W1.6mm_P2.50mm
CLK_U1: LM555xN; DIP-8_W7.62mm
CLK_U_C1, CLK_U_C3: C; C_Disc_D3.0mm_W1.6mm_P2.50mm
CLK_U_C2: 100 nF; C_Disc_D3.0mm_W1.6mm_P2.50mm
CLK_U_R1: R; R_Axial_DIN0204_L3.6mm_D1.6mm_P5.08mm_Horizontal

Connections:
+5V: CLKINVERTER_U1.14 (VCC), CLKINVERTER_U_C1.1, CLK_U1.4 (R), CLK_U1.8 (VCC), CLK_U_C2.1; also elsewhere on the board
/CLK: CLKINVERTER_U1.1, CLK_U1.3 (Q), CLK_U_R1.1; also elsewhere on the board
/~CLK: CLKINVERTER_U1.2; also elsewhere on the board
GND: CLKINVERTER_U1.7 (GND), CLKINVERTER_U_C1.2, CLK_U1.1 (GND), CLK_U_C1.2, CLK_U_C2.2, CLK_U_C3.2; also elsewhere on the board
unnamed: CLK_U1.5 (CV), CLK_U_C1.1
unnamed: CLK_U1.2 (TR), CLK_U1.6 (THR), CLK_U_C3.1, CLK_U_R1.2

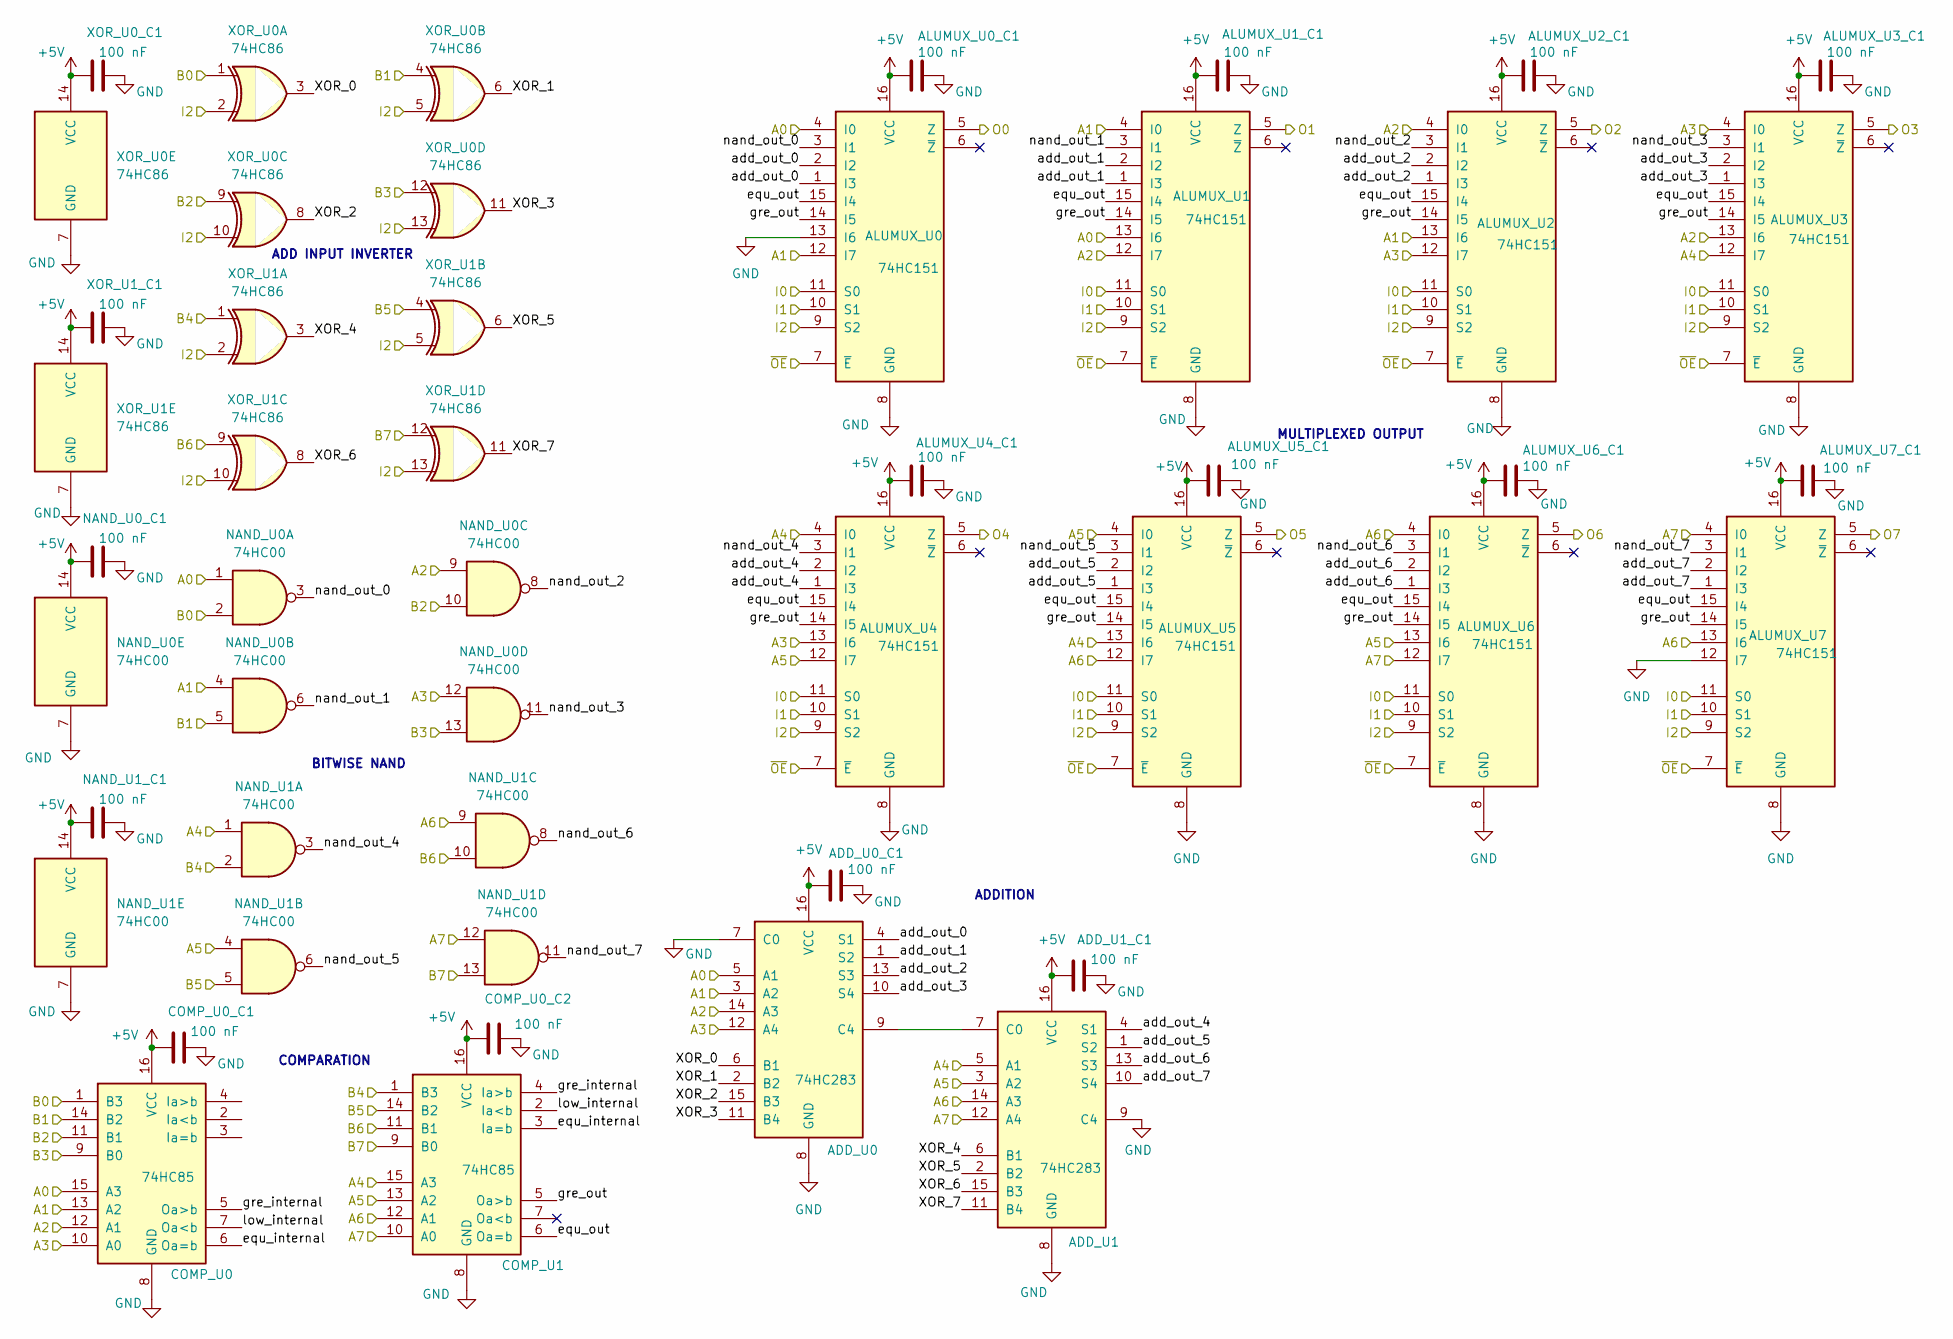
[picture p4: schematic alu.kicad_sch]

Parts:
ADD_U0, ADD_U1: 74HC283; DIP-16_W7.62mm
ADD_U0_C1, ADD_U1_C1: 100 nF; C_Disc_D3.0mm_W1.6mm_P2.50mm
ALUMUX_U0, ALUMUX_U1, ALUMUX_U2, ALUMUX_U3, ALUMUX_U4, ALUMUX_U5, ALUMUX_U6, ALUMUX_U7: 74HC151; DIP-16_W7.62mm
ALUMUX_U0_C1, ALUMUX_U1_C1, ALUMUX_U2_C1, ALUMUX_U3_C1, ALUMUX_U4_C1, ALUMUX_U5_C1, ALUMUX_U6_C1, ALUMUX_U7_C1: 100 nF; C_Disc_D3.0mm_W1.6mm_P2.50mm
COMP_U0, COMP_U1: 74HC85; DIP-16_W7.62mm
COMP_U0_C1, COMP_U0_C2: 100 nF; C_Disc_D3.0mm_W1.6mm_P2.50mm
NAND_U0, NAND_U1: 74HC00; DIP-14_W7.62mm
NAND_U0_C1, NAND_U1_C1: 100 nF; C_Disc_D3.0mm_W1.6mm_P2.50mm
XOR_U0, XOR_U1: 74HC86; DIP-14_W7.62mm
XOR_U0_C1, XOR_U1_C1: 100 nF; C_Disc_D3.0mm_W1.6mm_P2.50mm

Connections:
+5V: ADD_U0.16 (VCC), ADD_U0_C1.1, ADD_U1.16 (VCC), ADD_U1_C1.1, ALUMUX_U0.16 (VCC), ALUMUX_U0_C1.1, ALUMUX_U1.16 (VCC), ALUMUX_U1_C1.1, ALUMUX_U2.16 (VCC), ALUMUX_U2_C1.1, ALUMUX_U3.16 (VCC), ALUMUX_U3_C1.1, ALUMUX_U4.16 (VCC), ALUMUX_U4_C1.1, ALUMUX_U5.16 (VCC), ALUMUX_U5_C1.1, ALUMUX_U6.16 (VCC), ALUMUX_U6_C1.1, ALUMUX_U7.16 (VCC), ALUMUX_U7_C1.1, COMP_U0.16 (VCC), COMP_U0_C1.1, COMP_U0_C2.1, COMP_U1.16 (VCC), NAND_U0.14 (VCC), NAND_U0_C1.1, NAND_U1.14 (VCC), NAND_U1_C1.1, XOR_U0.14 (VCC), XOR_U0_C1.1, XOR_U1.14 (VCC), XOR_U1_C1.1; also elsewhere on the board
/ALU/A0: ADD_U0.5 (A1), ALUMUX_U0.4 (I0), ALUMUX_U1.13 (I6), COMP_U0.15 (A3), NAND_U0.1; also elsewhere on the board
/ALU/A1: ADD_U0.3 (A2), ALUMUX_U0.12 (I7), ALUMUX_U1.4 (I0), ALUMUX_U2.13 (I6), COMP_U0.13 (A2), NAND_U0.4; also elsewhere on the board
/ALU/A2: ADD_U0.14 (A3), ALUMUX_U1.12 (I7), ALUMUX_U2.4 (I0), ALUMUX_U3.13 (I6), COMP_U0.12 (A1), NAND_U0.9; also elsewhere on the board
/ALU/A3: ADD_U0.12 (A4), ALUMUX_U2.12 (I7), ALUMUX_U3.4 (I0), ALUMUX_U4.13 (I6), COMP_U0.10 (A0), NAND_U0.12; also elsewhere on the board
/ALU/A4: ADD_U1.5 (A1), ALUMUX_U3.12 (I7), ALUMUX_U4.4 (I0), ALUMUX_U5.13 (I6), COMP_U1.15 (A3), NAND_U1.1; also elsewhere on the board
/ALU/A5: ADD_U1.3 (A2), ALUMUX_U4.12 (I7), ALUMUX_U5.4 (I0), ALUMUX_U6.13 (I6), COMP_U1.13 (A2), NAND_U1.4; also elsewhere on the board
/ALU/A6: ADD_U1.14 (A3), ALUMUX_U5.12 (I7), ALUMUX_U6.4 (I0), ALUMUX_U7.13 (I6), COMP_U1.12 (A1), NAND_U1.9; also elsewhere on the board
/ALU/A7: ADD_U1.12 (A4), ALUMUX_U6.12 (I7), ALUMUX_U7.4 (I0), COMP_U1.10 (A0), NAND_U1.12; also elsewhere on the board
/ALU/B0: COMP_U0.1 (B3), NAND_U0.2, XOR_U0.1; also elsewhere on the board
/ALU/B1: COMP_U0.14 (B2), NAND_U0.5, XOR_U0.4; also elsewhere on the board
/ALU/B2: COMP_U0.11 (B1), NAND_U0.10, XOR_U0.9; also elsewhere on the board
/ALU/B3: COMP_U0.9 (B0), NAND_U0.13, XOR_U0.12; also elsewhere on the board
/ALU/B4: COMP_U1.1 (B3), NAND_U1.2, XOR_U1.1; also elsewhere on the board
/ALU/B5: COMP_U1.14 (B2), NAND_U1.5, XOR_U1.4; also elsewhere on the board
/ALU/B6: COMP_U1.11 (B1), NAND_U1.10, XOR_U1.9; also elsewhere on the board
/ALU/B7: COMP_U1.9 (B0), NAND_U1.13, XOR_U1.12; also elsewhere on the board
/ALU/XOR_0: ADD_U0.6 (B1), XOR_U0.3
/ALU/XOR_1: ADD_U0.2 (B2), XOR_U0.6
/ALU/XOR_2: ADD_U0.15 (B3), XOR_U0.8
/ALU/XOR_3: ADD_U0.11 (B4), XOR_U0.11
/ALU/XOR_4: ADD_U1.6 (B1), XOR_U1.3
/ALU/XOR_5: ADD_U1.2 (B2), XOR_U1.6
/ALU/XOR_6: ADD_U1.15 (B3), XOR_U1.8
/ALU/XOR_7: ADD_U1.11 (B4), XOR_U1.11
/ALU/add_out_0: ADD_U0.4 (S1), ALUMUX_U0.1 (I3), ALUMUX_U0.2 (I2)
/ALU/add_out_1: ADD_U0.1 (S2), ALUMUX_U1.1 (I3), ALUMUX_U1.2 (I2)
/ALU/add_out_2: ADD_U0.13 (S3), ALUMUX_U2.1 (I3), ALUMUX_U2.2 (I2)
/ALU/add_out_3: ADD_U0.10 (S4), ALUMUX_U3.1 (I3), ALUMUX_U3.2 (I2)
/ALU/add_out_4: ADD_U1.4 (S1), ALUMUX_U4.1 (I3), ALUMUX_U4.2 (I2)
/ALU/add_out_5: ADD_U1.1 (S2), ALUMUX_U5.1 (I3), ALUMUX_U5.2 (I2)
/ALU/add_out_6: ADD_U1.13 (S3), ALUMUX_U6.1 (I3), ALUMUX_U6.2 (I2)
/ALU/add_out_7: ADD_U1.10 (S4), ALUMUX_U7.1 (I3), ALUMUX_U7.2 (I2)
/ALU/equ_internal: COMP_U0.6 (Oa=b), COMP_U1.3 (Ia=b)
/ALU/equ_out: ALUMUX_U0.15 (I4), ALUMUX_U1.15 (I4), ALUMUX_U2.15 (I4), ALUMUX_U3.15 (I4), ALUMUX_U4.15 (I4), ALUMUX_U5.15 (I4), ALUMUX_U6.15 (I4), ALUMUX_U7.15 (I4), COMP_U1.6 (Oa=b)
/ALU/gre_internal: COMP_U0.5 (Oa>b), COMP_U1.4 (Ia>b)
/ALU/gre_out: ALUMUX_U0.14 (I5), ALUMUX_U1.14 (I5), ALUMUX_U2.14 (I5), ALUMUX_U3.14 (I5), ALUMUX_U4.14 (I5), ALUMUX_U5.14 (I5), ALUMUX_U6.14 (I5), ALUMUX_U7.14 (I5), COMP_U1.5 (Oa>b)
/ALU/low_internal: COMP_U0.7 (Oa<b), COMP_U1.2 (Ia<b)
/ALU/nand_out_0: ALUMUX_U0.3 (I1), NAND_U0.3
/ALU/nand_out_1: ALUMUX_U1.3 (I1), NAND_U0.6
/ALU/nand_out_2: ALUMUX_U2.3 (I1), NAND_U0.8
/ALU/nand_out_3: ALUMUX_U3.3 (I1), NAND_U0.11
/ALU/nand_out_4: ALUMUX_U4.3 (I1), NAND_U1.3
/ALU/nand_out_5: ALUMUX_U5.3 (I1), NAND_U1.6
/ALU/nand_out_6: ALUMUX_U6.3 (I1), NAND_U1.8
/ALU/nand_out_7: ALUMUX_U7.3 (I1), NAND_U1.11
/BUS_0: ALUMUX_U0.5 (Z); also elsewhere on the board
/BUS_1: ALUMUX_U1.5 (Z); also elsewhere on the board
/BUS_2: ALUMUX_U2.5 (Z); also elsewhere on the board
/BUS_3: ALUMUX_U3.5 (Z); also elsewhere on the board
/BUS_4: ALUMUX_U4.5 (Z); also elsewhere on the board
/BUS_5: ALUMUX_U5.5 (Z); also elsewhere on the board
/BUS_6: ALUMUX_U6.5 (Z); also elsewhere on the board
/BUS_7: ALUMUX_U7.5 (Z); also elsewhere on the board
/IR_OUT_5: ALUMUX_U0.11 (S0), ALUMUX_U1.11 (S0), ALUMUX_U2.11 (S0), ALUMUX_U3.11 (S0), ALUMUX_U4.11 (S0), ALUMUX_U5.11 (S0), ALUMUX_U6.11 (S0), ALUMUX_U7.11 (S0); also elsewhere on the board
/IR_OUT_6: ALUMUX_U0.10 (S1), ALUMUX_U1.10 (S1), ALUMUX_U2.10 (S1), ALUMUX_U3.10 (S1), ALUMUX_U4.10 (S1), ALUMUX_U5.10 (S1), ALUMUX_U6.10 (S1), ALUMUX_U7.10 (S1); also elsewhere on the board
/IR_OUT_7: ALUMUX_U0.9 (S2), ALUMUX_U1.9 (S2), ALUMUX_U2.9 (S2), ALUMUX_U3.9 (S2), ALUMUX_U4.9 (S2), ALUMUX_U5.9 (S2), ALUMUX_U6.9 (S2), ALUMUX_U7.9 (S2), XOR_U0.2, XOR_U0.5, XOR_U0.10, XOR_U0.13, XOR_U1.2, XOR_U1.5, XOR_U1.10, XOR_U1.13; also elsewhere on the board
/~ALU_OE: ALUMUX_U0.7 (~E), ALUMUX_U1.7 (~E), ALUMUX_U2.7 (~E), ALUMUX_U3.7 (~E), ALUMUX_U4.7 (~E), ALUMUX_U5.7 (~E), ALUMUX_U6.7 (~E), ALUMUX_U7.7 (~E); also elsewhere on the board
GND: ADD_U0.7 (C0), ADD_U0.8 (GND), ADD_U0_C1.2, ADD_U1.8 (GND), ADD_U1.9 (C4), ADD_U1_C1.2, ALUMUX_U0.8 (GND), ALUMUX_U0.13 (I6), ALUMUX_U0_C1.2, ALUMUX_U1.8 (GND), ALUMUX_U1_C1.2, ALUMUX_U2.8 (GND), ALUMUX_U2_C1.2, ALUMUX_U3.8 (GND), ALUMUX_U3_C1.2, ALUMUX_U4.8 (GND), ALUMUX_U4_C1.2, ALUMUX_U5.8 (GND), ALUMUX_U5_C1.2, ALUMUX_U6.8 (GND), ALUMUX_U6_C1.2, ALUMUX_U7.8 (GND), ALUMUX_U7.12 (I7), ALUMUX_U7_C1.2, COMP_U0.8 (GND), COMP_U0_C1.2, COMP_U0_C2.2, COMP_U1.8 (GND), NAND_U0.7 (GND), NAND_U0_C1.2, NAND_U1.7 (GND), NAND_U1_C1.2, XOR_U0.7 (GND), XOR_U0_C1.2, XOR_U1.7 (GND), XOR_U1_C1.2; also elsewhere on the board
unnamed: ADD_U0.9 (C4), ADD_U1.7 (C0)

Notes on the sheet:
BITWISE NAND
MULTIPLEXED OUTPUT
COMPARATION
ADDITION
ADD INPUT INVERTER

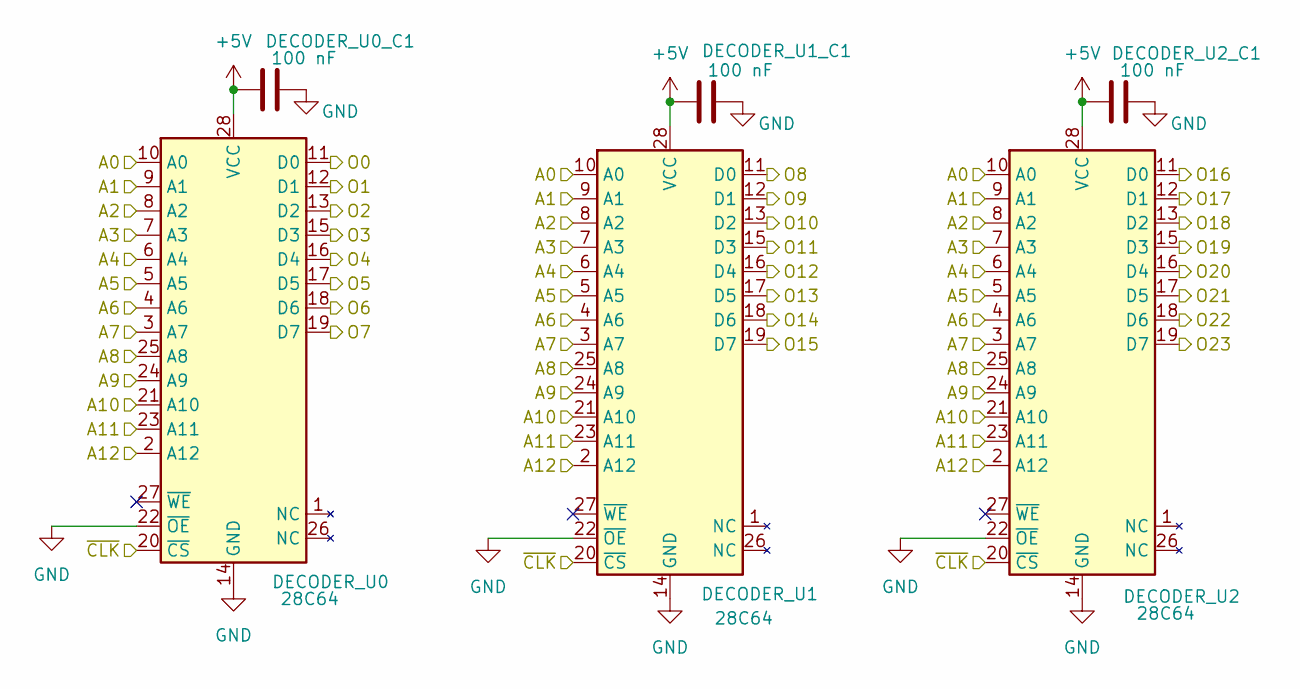
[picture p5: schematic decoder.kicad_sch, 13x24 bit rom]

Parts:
DECODER_U0, DECODER_U1, DECODER_U2: 28C64; DIP-28_W15.24mm
DECODER_U0_C1, DECODER_U1_C1, DECODER_U2_C1: 100 nF; C_Disc_D3.0mm_W1.6mm_P2.50mm

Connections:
+5V: DECODER_U0.28 (VCC), DECODER_U0_C1.1, DECODER_U1.28 (VCC), DECODER_U1_C1.1, DECODER_U2.28 (VCC), DECODER_U2_C1.1; also elsewhere on the board
/ADR0_I: DECODER_U0.18 (D6); also elsewhere on the board
/ADR12_I: DECODER_U1.15 (D3); also elsewhere on the board
/CLK: DECODER_U0.20 (~CS), DECODER_U1.20 (~CS), DECODER_U2.20 (~CS); also elsewhere on the board
/IC_0: DECODER_U0.25 (A8), DECODER_U1.25 (A8), DECODER_U2.25 (A8); also elsewhere on the board
/IC_1: DECODER_U0.24 (A9), DECODER_U1.24 (A9), DECODER_U2.24 (A9); also elsewhere on the board
/IC_2: DECODER_U0.21 (A10), DECODER_U1.21 (A10), DECODER_U2.21 (A10); also elsewhere on the board
/IC_3: DECODER_U0.23 (A11), DECODER_U1.23 (A11), DECODER_U2.23 (A11); also elsewhere on the board
/IR_OUT_0: DECODER_U0.10 (A0), DECODER_U1.10 (A0), DECODER_U2.10 (A0); also elsewhere on the board
/IR_OUT_1: DECODER_U0.9 (A1), DECODER_U1.9 (A1), DECODER_U2.9 (A1); also elsewhere on the board
/IR_OUT_2: DECODER_U0.8 (A2), DECODER_U1.8 (A2), DECODER_U2.8 (A2); also elsewhere on the board
/IR_OUT_3: DECODER_U0.7 (A3), DECODER_U1.7 (A3), DECODER_U2.7 (A3); also elsewhere on the board
/IR_OUT_4: DECODER_U0.6 (A4), DECODER_U1.6 (A4), DECODER_U2.6 (A4); also elsewhere on the board
/IR_OUT_5: DECODER_U0.5 (A5), DECODER_U1.5 (A5), DECODER_U2.5 (A5); also elsewhere on the board
/IR_OUT_6: DECODER_U0.4 (A6), DECODER_U1.4 (A6), DECODER_U2.4 (A6); also elsewhere on the board
/IR_OUT_7: DECODER_U0.3 (A7), DECODER_U1.3 (A7), DECODER_U2.3 (A7); also elsewhere on the board
/PC_I: DECODER_U1.16 (D4); also elsewhere on the board
/SWT: DECODER_U1.18 (D6); also elsewhere on the board
/~ADR0_WE: DECODER_U0.17 (D5); also elsewhere on the board
/~ADR1_WE: DECODER_U1.12 (D1); also elsewhere on the board
/~ADR2_WE: DECODER_U1.13 (D2); also elsewhere on the board
/~ALU_OE: DECODER_U0.13 (D2); also elsewhere on the board
/~AUX_OE: DECODER_U0.16 (D4); also elsewhere on the board
/~AUX_WE: DECODER_U0.15 (D3)
/~DTA_WE: DECODER_U0.11 (D0); also elsewhere on the board
/~DTB_WE: DECODER_U0.12 (D1); also elsewhere on the board
/~IC_R: DECODER_U2.17 (D5); also elsewhere on the board
/~INP_FLAG_OE: DECODER_U2.16 (D4); also elsewhere on the board
/~INP_OE: DECODER_U2.15 (D3)
/~INS_WE: DECODER_U2.18 (D6); also elsewhere on the board
/~OUT_FLAG_OE: DECODER_U2.13 (D2); also elsewhere on the board
/~OUT_WE: DECODER_U2.12 (D1); also elsewhere on the board
/~PC_WE: DECODER_U1.17 (D5); also elsewhere on the board
/~RAM_OE: DECODER_U1.11 (D0); also elsewhere on the board
/~RAM_WE: DECODER_U0.19 (D7); also elsewhere on the board
/~ROM_OE: DECODER_U2.11 (D0); also elsewhere on the board
/~ROM_WE: DECODER_U1.19 (D7); also elsewhere on the board
GND: DECODER_U0.2 (A12), DECODER_U0.14 (GND), DECODER_U0.22 (~OE), DECODER_U0_C1.2, DECODER_U1.2 (A12), DECODER_U1.14 (GND), DECODER_U1.22 (~OE), DECODER_U1_C1.2, DECODER_U2.2 (A12), DECODER_U2.14 (GND), DECODER_U2.19 (D7), DECODER_U2.22 (~OE), DECODER_U2_C1.2; also elsewhere on the board

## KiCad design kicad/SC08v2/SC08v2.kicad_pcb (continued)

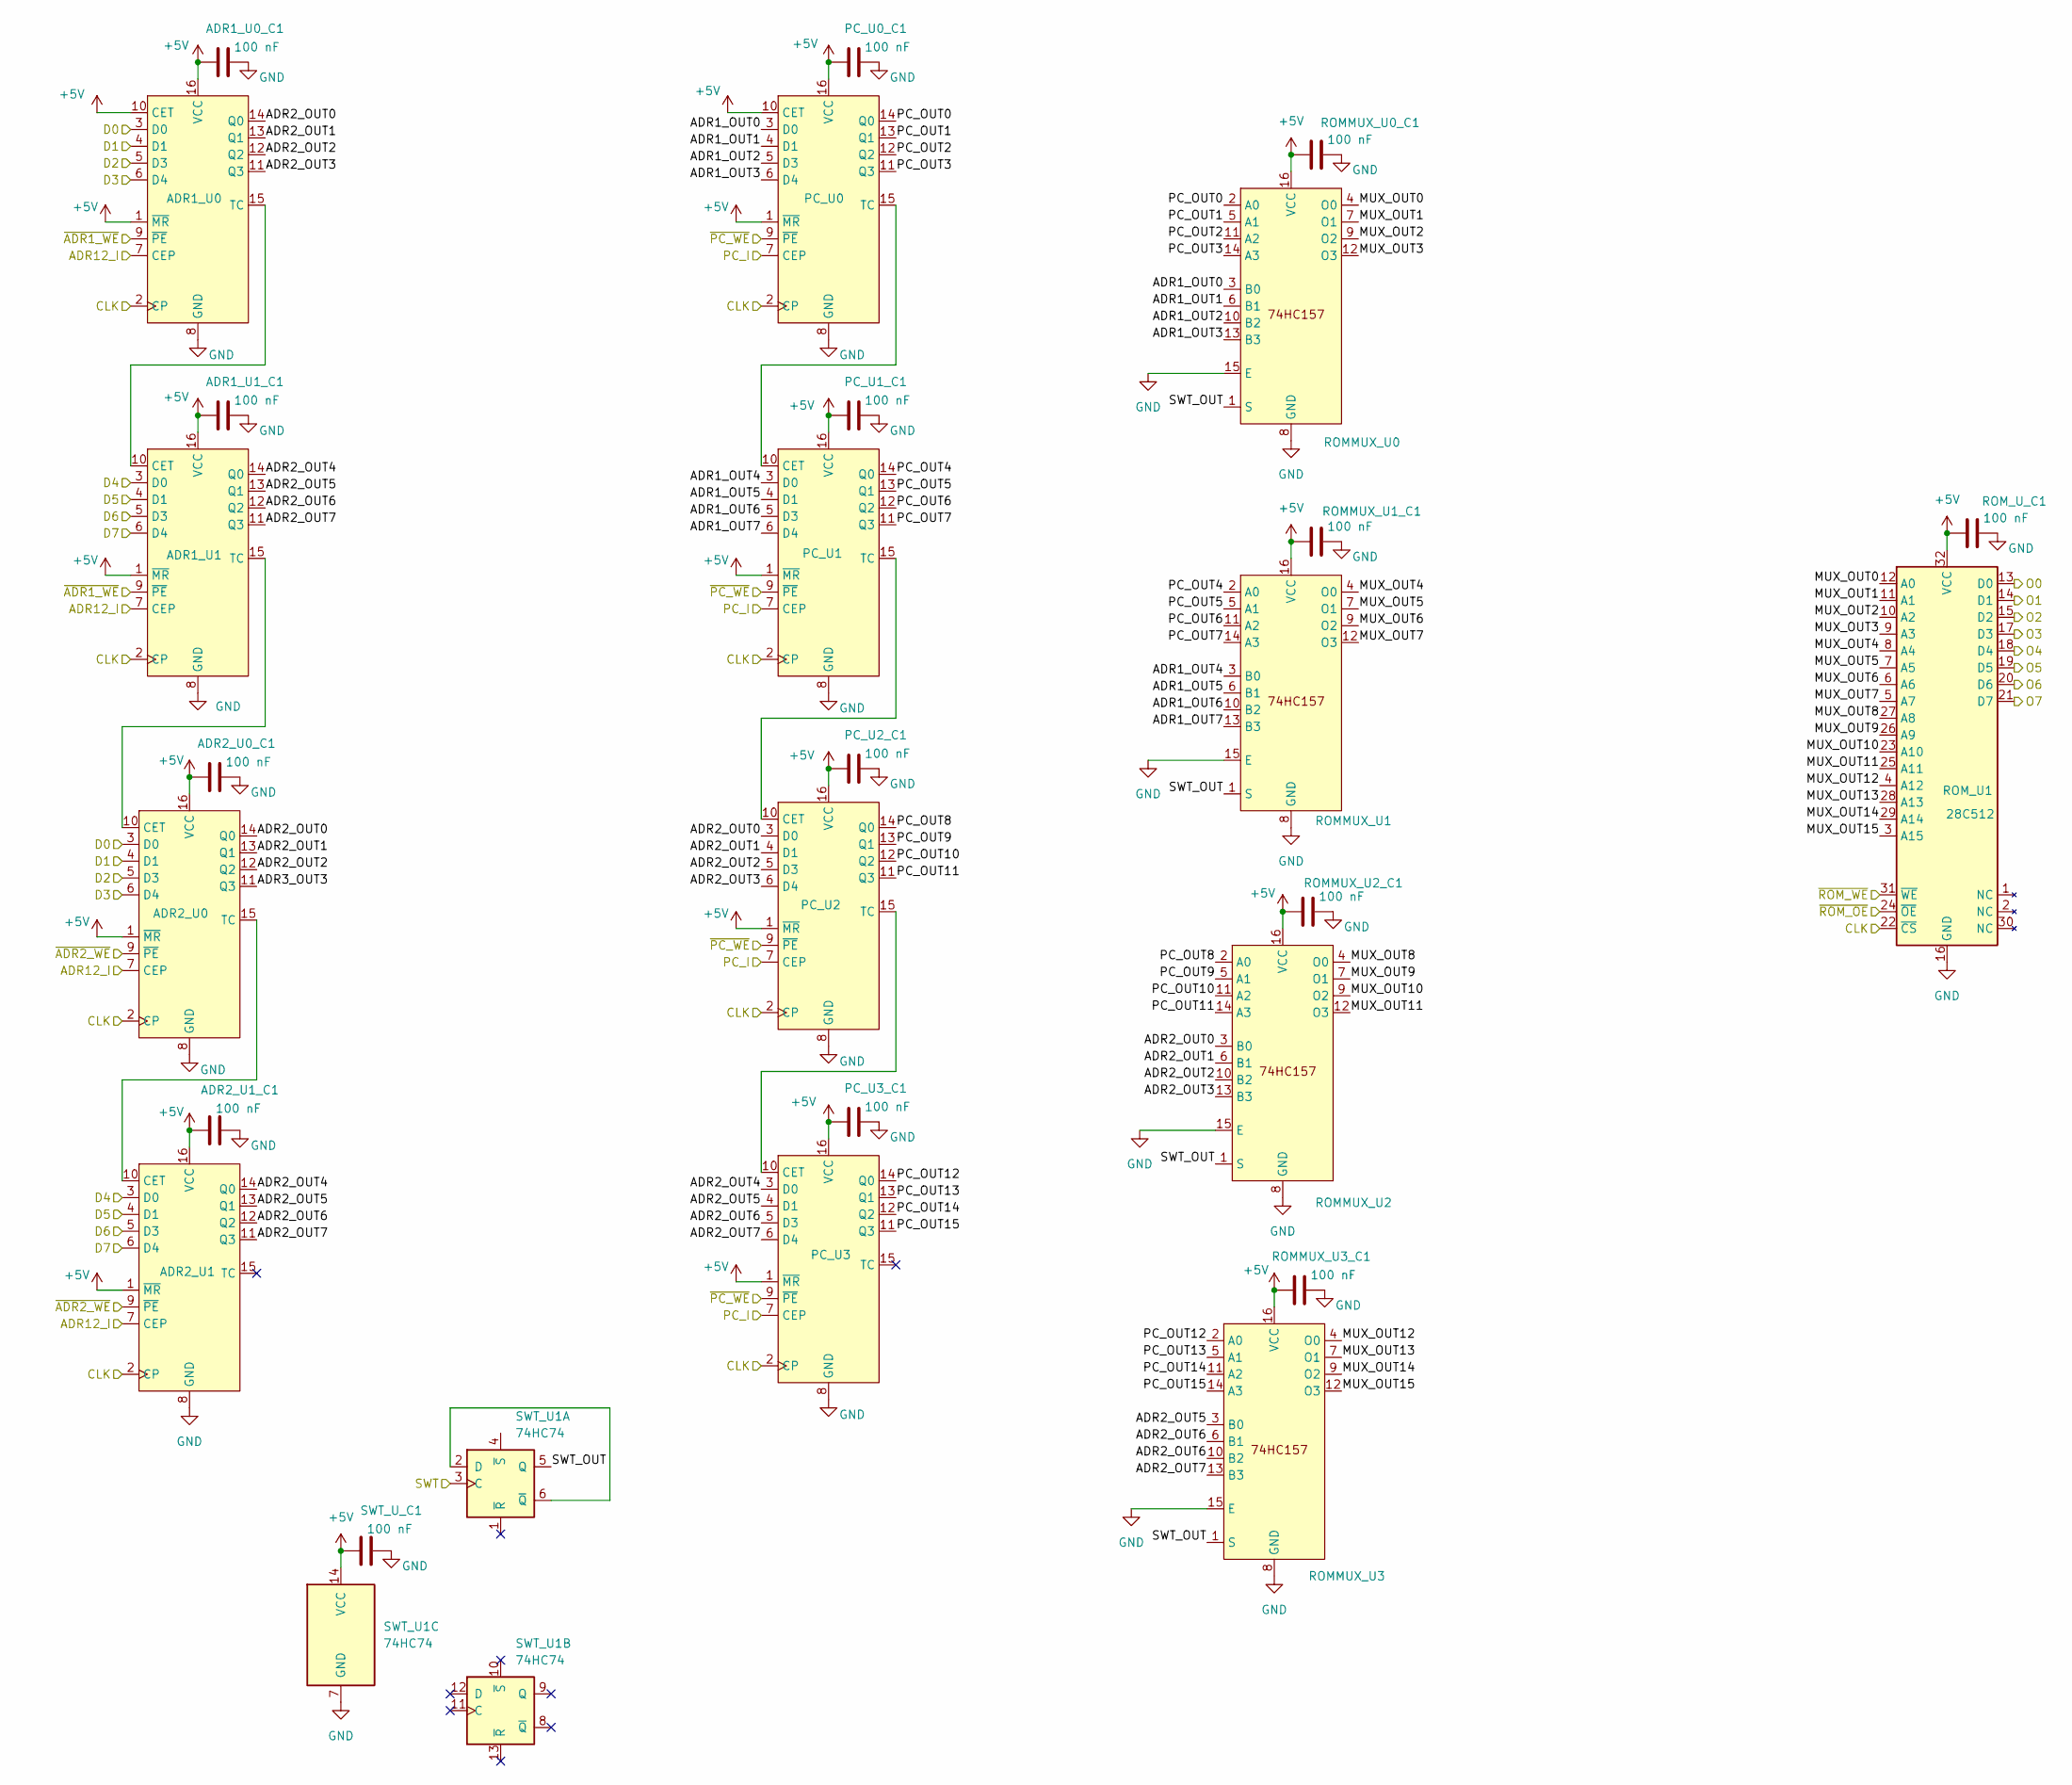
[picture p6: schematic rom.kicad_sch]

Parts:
ADR1_U0, ADR1_U1, ADR2_U0, ADR2_U1: DIP-16_W7.62mm
ADR1_U0_C1, ADR1_U1_C1, ADR2_U0_C1, ADR2_U1_C1: 100 nF; C_Disc_D3.0mm_W1.6mm_P2.50mm
PC_U0, PC_U1, PC_U2, PC_U3: DIP-16_W7.62mm
PC_U0_C1, PC_U1_C1, PC_U2_C1, PC_U3_C1: 100 nF; C_Disc_D3.0mm_W1.6mm_P2.50mm
ROMMUX_U0, ROMMUX_U1, ROMMUX_U2, ROMMUX_U3: DIP-16_W7.62mm
ROMMUX_U0_C1, ROMMUX_U1_C1, ROMMUX_U2_C1, ROMMUX_U3_C1: 100 nF; C_Disc_D3.0mm_W1.6mm_P2.50mm
ROM_U1: 28C512; DIP-32_W15.24mm
ROM_U_C1: 100 nF; C_Disc_D3.0mm_W1.6mm_P2.50mm
SWT_U1: 74HC74; DIP-14_W7.62mm
SWT_U_C1: 100 nF; C_Disc_D3.0mm_W1.6mm_P2.50mm

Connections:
+5V: ADR1_U0.1 (~MR), ADR1_U0.10 (CET), ADR1_U0.16 (VCC), ADR1_U0_C1.1, ADR1_U1.1 (~MR), ADR1_U1.16 (VCC), ADR1_U1_C1.1, ADR2_U0.1 (~MR), ADR2_U0.16 (VCC), ADR2_U0_C1.1, ADR2_U1.1 (~MR), ADR2_U1.16 (VCC), ADR2_U1_C1.1, PC_U0.1 (~MR), PC_U0.10 (CET), PC_U0.16 (VCC), PC_U0_C1.1, PC_U1.1 (~MR), PC_U1.16 (VCC), PC_U1_C1.1, PC_U2.1 (~MR), PC_U2.16 (VCC), PC_U2_C1.1, PC_U3.1 (~MR), PC_U3.16 (VCC), PC_U3_C1.1, ROMMUX_U0.16 (VCC), ROMMUX_U0_C1.1, ROMMUX_U1.16 (VCC), ROMMUX_U1_C1.1, ROMMUX_U2.16 (VCC), ROMMUX_U2_C1.1, ROMMUX_U3.16 (VCC), ROMMUX_U3_C1.1, ROM_U1.32 (VCC), ROM_U_C1.1, SWT_U1.14 (VCC), SWT_U_C1.1; also elsewhere on the board
/ADR12_I: ADR1_U0.7 (CEP), ADR1_U1.7 (CEP), ADR2_U0.7 (CEP), ADR2_U1.7 (CEP); also elsewhere on the board
/BUS_0: ADR1_U0.3 (D0), ADR2_U0.3 (D0), ROM_U1.13 (D0); also elsewhere on the board
/BUS_1: ADR1_U0.4 (D1), ADR2_U0.4 (D1), ROM_U1.14 (D1); also elsewhere on the board
/BUS_2: ADR1_U0.5 (D3), ADR2_U0.5 (D3), ROM_U1.15 (D2); also elsewhere on the board
/BUS_3: ADR1_U0.6 (D4), ADR2_U0.6 (D4), ROM_U1.17 (D3); also elsewhere on the board
/BUS_4: ADR1_U1.3 (D0), ADR2_U1.3 (D0), ROM_U1.18 (D4); also elsewhere on the board
/BUS_5: ADR1_U1.4 (D1), ADR2_U1.4 (D1), ROM_U1.19 (D5); also elsewhere on the board
/BUS_6: ADR1_U1.5 (D3), ADR2_U1.5 (D3), ROM_U1.20 (D6); also elsewhere on the board
/BUS_7: ADR1_U1.6 (D4), ADR2_U1.6 (D4), ROM_U1.21 (D7); also elsewhere on the board
/CLK: ADR1_U0.2 (CP), ADR1_U1.2 (CP), ADR2_U0.2 (CP), ADR2_U1.2 (CP), PC_U0.2 (CP), PC_U1.2 (CP), PC_U2.2 (CP), PC_U3.2 (CP), ROM_U1.22 (~CS); also elsewhere on the board
/PC_I: PC_U0.7 (CEP), PC_U1.7 (CEP), PC_U2.7 (CEP), PC_U3.7 (CEP); also elsewhere on the board
/ROM/ADR1_OUT0: PC_U0.3 (D0), ROMMUX_U0.3 (B0)
/ROM/ADR1_OUT1: PC_U0.4 (D1), ROMMUX_U0.6 (B1)
/ROM/ADR1_OUT2: PC_U0.5 (D3), ROMMUX_U0.10 (B2)
/ROM/ADR1_OUT3: PC_U0.6 (D4), ROMMUX_U0.13 (B3)
/ROM/ADR1_OUT4: PC_U1.3 (D0), ROMMUX_U1.3 (B0)
/ROM/ADR1_OUT5: PC_U1.4 (D1), ROMMUX_U1.6 (B1)
/ROM/ADR1_OUT6: PC_U1.5 (D3), ROMMUX_U1.10 (B2)
/ROM/ADR1_OUT7: PC_U1.6 (D4), ROMMUX_U1.13 (B3)
/ROM/ADR2_OUT0: ADR1_U0.14 (Q0), ADR2_U0.14 (Q0), PC_U2.3 (D0), ROMMUX_U2.3 (B0)
/ROM/ADR2_OUT1: ADR1_U0.13 (Q1), ADR2_U0.13 (Q1), PC_U2.4 (D1), ROMMUX_U2.6 (B1)
/ROM/ADR2_OUT2: ADR1_U0.12 (Q2), ADR2_U0.12 (Q2), PC_U2.5 (D3), ROMMUX_U2.10 (B2)
/ROM/ADR2_OUT3: ADR1_U0.11 (Q3), PC_U2.6 (D4), ROMMUX_U2.13 (B3)
/ROM/ADR2_OUT4: ADR1_U1.14 (Q0), ADR2_U1.14 (Q0), PC_U3.3 (D0)
/ROM/ADR2_OUT5: ADR1_U1.13 (Q1), ADR2_U1.13 (Q1), PC_U3.4 (D1), ROMMUX_U3.3 (B0)
/ROM/ADR2_OUT6: ADR1_U1.12 (Q2), ADR2_U1.12 (Q2), PC_U3.5 (D3), ROMMUX_U3.6 (B1), ROMMUX_U3.10 (B2)
/ROM/ADR2_OUT7: ADR1_U1.11 (Q3), ADR2_U1.11 (Q3), PC_U3.6 (D4), ROMMUX_U3.13 (B3)
/ROM/ADR3_OUT3: ADR2_U0.11 (Q3)
/ROM/MUX_OUT0: ROMMUX_U0.4 (O0), ROM_U1.12 (A0)
/ROM/MUX_OUT1: ROMMUX_U0.7 (O1), ROM_U1.11 (A1)
/ROM/MUX_OUT2: ROMMUX_U0.9 (O2), ROM_U1.10 (A2)
/ROM/MUX_OUT3: ROMMUX_U0.12 (O3), ROM_U1.9 (A3)
/ROM/MUX_OUT4: ROMMUX_U1.4 (O0), ROM_U1.8 (A4)
/ROM/MUX_OUT5: ROMMUX_U1.7 (O1), ROM_U1.7 (A5)
/ROM/MUX_OUT6: ROMMUX_U1.9 (O2), ROM_U1.6 (A6)
/ROM/MUX_OUT7: ROMMUX_U1.12 (O3), ROM_U1.5 (A7)
/ROM/MUX_OUT8: ROMMUX_U2.4 (O0), ROM_U1.27 (A8)
/ROM/MUX_OUT9: ROMMUX_U2.7 (O1), ROM_U1.26 (A9)
/ROM/MUX_OUT10: ROMMUX_U2.9 (O2), ROM_U1.23 (A10)
/ROM/MUX_OUT11: ROMMUX_U2.12 (O3), ROM_U1.25 (A11)
/ROM/MUX_OUT12: ROMMUX_U3.4 (O0), ROM_U1.4 (A12)
/ROM/MUX_OUT13: ROMMUX_U3.7 (O1), ROM_U1.28 (A13)
/ROM/MUX_OUT14: ROMMUX_U3.9 (O2), ROM_U1.29 (A14)
/ROM/MUX_OUT15: ROMMUX_U3.12 (O3), ROM_U1.3 (A15)
/ROM/PC_OUT0: PC_U0.14 (Q0), ROMMUX_U0.2 (A0)
/ROM/PC_OUT1: PC_U0.13 (Q1), ROMMUX_U0.5 (A1)
/ROM/PC_OUT2: PC_U0.12 (Q2), ROMMUX_U0.11 (A2)
/ROM/PC_OUT3: PC_U0.11 (Q3), ROMMUX_U0.14 (A3)
/ROM/PC_OUT4: PC_U1.14 (Q0), ROMMUX_U1.2 (A0)
/ROM/PC_OUT5: PC_U1.13 (Q1), ROMMUX_U1.5 (A1)
/ROM/PC_OUT6: PC_U1.12 (Q2), ROMMUX_U1.11 (A2)
/ROM/PC_OUT7: PC_U1.11 (Q3), ROMMUX_U1.14 (A3)
/ROM/PC_OUT8: PC_U2.14 (Q0), ROMMUX_U2.2 (A0)
/ROM/PC_OUT9: PC_U2.13 (Q1), ROMMUX_U2.5 (A1)
/ROM/PC_OUT10: PC_U2.12 (Q2), ROMMUX_U2.11 (A2)
/ROM/PC_OUT11: PC_U2.11 (Q3), ROMMUX_U2.14 (A3)
/ROM/PC_OUT12: PC_U3.14 (Q0), ROMMUX_U3.2 (A0)
/ROM/PC_OUT13: PC_U3.13 (Q1), ROMMUX_U3.5 (A1)
/ROM/PC_OUT14: PC_U3.12 (Q2), ROMMUX_U3.11 (A2)
/ROM/PC_OUT15: PC_U3.11 (Q3), ROMMUX_U3.14 (A3)
/ROM/SWT_OUT: ROMMUX_U0.1 (S), ROMMUX_U1.1 (S), ROMMUX_U2.1 (S), ROMMUX_U3.1 (S), SWT_U1.5 (Q)
/SWT: SWT_U1.3 (C); also elsewhere on the board
/~ADR1_WE: ADR1_U0.9 (~PE), ADR1_U1.9 (~PE); also elsewhere on the board
/~ADR2_WE: ADR2_U0.9 (~PE), ADR2_U1.9 (~PE); also elsewhere on the board
/~PC_WE: PC_U0.9 (~PE), PC_U1.9 (~PE), PC_U2.9 (~PE), PC_U3.9 (~PE); also elsewhere on the board
/~ROM_OE: ROM_U1.24 (~OE); also elsewhere on the board
/~ROM_WE: ROM_U1.31 (~WE); also elsewhere on the board
GND: ADR1_U0.8 (GND), ADR1_U0_C1.2, ADR1_U1.8 (GND), ADR1_U1_C1.2, ADR2_U0.8 (GND), ADR2_U0_C1.2, ADR2_U1.8 (GND), ADR2_U1_C1.2, PC_U0.8 (GND), PC_U0_C1.2, PC_U1.8 (GND), PC_U1_C1.2, PC_U2.8 (GND), PC_U2_C1.2, PC_U3.8 (GND), PC_U3_C1.2, ROMMUX_U0.8 (GND), ROMMUX_U0.15 (E), ROMMUX_U0_C1.2, ROMMUX_U1.8 (GND), ROMMUX_U1.15 (E), ROMMUX_U1_C1.2, ROMMUX_U2.8 (GND), ROMMUX_U2.15 (E), ROMMUX_U2_C1.2, ROMMUX_U3.8 (GND), ROMMUX_U3.15 (E), ROMMUX_U3_C1.2, ROM_U1.16 (GND), ROM_U_C1.2, SWT_U1.7 (GND), SWT_U_C1.2; also elsewhere on the board
unnamed: ADR1_U0.15 (TC), ADR1_U1.10 (CET)
unnamed: ADR1_U1.15 (TC), ADR2_U0.10 (CET)
unnamed: ADR2_U0.15 (TC), ADR2_U1.10 (CET)
unnamed: PC_U0.15 (TC), PC_U1.10 (CET)
unnamed: PC_U1.15 (TC), PC_U2.10 (CET)
unnamed: PC_U2.15 (TC), PC_U3.10 (CET)
unnamed: SWT_U1.2 (D), SWT_U1.6 (~Q)

Board: 4 copper layers, 116 parts (0 on the bottom side), 197 nets, no tracks yet.

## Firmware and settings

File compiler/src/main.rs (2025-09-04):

use std::env;
use std::fs;

mod compiler;
mod syntax_tree;

fn main() {
    let args: Vec<String> = env::args().collect();
    if args.len() != 2 {
        panic!("Argument #1 missing: source file path");
    }

    let file_contents = fs::read_to_string(&args[1]).unwrap();
    let code = syntax_tree::clean(&file_contents);
    let tree = syntax_tree::TreeNode::from(&code);
    let asm = compiler::compile(&tree);
    for e in asm {
        println!("{}\t{}\t{}", e.0, e.1, e.2);
    }
}

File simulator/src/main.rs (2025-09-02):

use std::env;
use std::num::Wrapping;
mod cpu;
mod instruction;

use cpu::*;

fn main() {
    let args: Vec<String> = env::args().collect();
    if args.len() != 2 {
        panic!("No ROM file given.");
    }

    let mut cpu = CpuStruct {
        dta: Wrapping(0),
        aux: Wrapping(0),
        ins: Wrapping(0),
        prc: Wrapping(0),
        adr: Wrapping(0),
        ic: Wrapping(0),
        swt: false,
        ram: [Wrapping(0); 256],
        rom: [Wrapping(0); 65536]
    };

    // Read program from ROM memory.
    let bytes = std::fs::read(&args[1]).expect("Error while reading ROM file");
    let mut i = 0;
    for b in bytes {
        cpu.rom[i] = Wrapping(b);
        i += 1;
    }

//    println!("steps:");
    let mut step = 0;
    loop {
//        println!("- instruction: {}", match cpu.ins.0 {
//            0b00000_000 => "NOI.noa",
//            0b00001_001 => "JUM.num",
//            0b01000_001 => "LDD.num",
//            0b01000_010 => "LDD.ram",
//            0b01000_011 => "LDD.rom",
//            0b01000_100 => "LDD.ptr",
//            0b01000_101 => "LDD.prr",
//            0b01000_110 => "LDD.inp",
//            0b01001_010 => "STD.ram",
//            0b01001_100 => "STD.ptr",
//            0b01001_101 => "STD.prr",
//            0b01001_111 => "STD.out",
//            0b10000_001 => "ADD.num",
//            0b10001_001 => "SUB.num",
//            0b10010_001 => "NAN.num",
//            0b10100_001 => "SHL.num",
//            0b10101_001 => "SHR.num",
//            0b10110_001 => "EQU.num",
//            0b10111_001 => "GRE.num",
//            0b10000_010 => "ADD.ram",
//            0b10001_010 => "SUB.ram",
//            0b10010_010 => "NAN.ram",
//            0b10100_010 => "SHL.ram",
//            0b10101_010 => "SHR.ram",
//            0b10110_010 => "EQU.ram",
//            0b10111_010 => "GRE.ram",
//            _ => "ERR",
//        });
//        println!("  state:");
//        println!("    ic:  {:#04x}", cpu.ic);
//        println!("    prc: {:#04x}", cpu.prc);
//        println!("    ins: {:#04x}", cpu.ins);
//        println!("    dta: {:#04x}", cpu.dta);
//        println!("    aux: {:#04x}", cpu.aux);
//        println!("    adr: {:#04x}", cpu.adr);
//        println!("  step: {}", step);

        if step == 10000 {
            break;
        }

        match cpu.ins.0 {
            // 0b0_<INS>_<SUB>
            0b00001_001 => instruction::jum_num(&mut cpu),
            0b01000_001 => instruction::ldd_num(&mut cpu),
            0b01000_010 => instruction::ldd_ram(&mut cpu),
            0b01000_011 => instruction::ldd_rom(&mut cpu),
            0b01000_100 => instruction::ldd_ptr(&mut cpu),
            0b01000_101 => instruction::ldd_prr(&mut cpu),
            0b01000_110 => instruction::ldd_inp(&mut cpu),
            0b01001_010 => instruction::std_ram(&mut cpu),
            0b01001_100 => instruction::std_ptr(&mut cpu),
            0b01001_101 => instruction::std_prr(&mut cpu),
            0b01001_111 => instruction::std_out(&mut cpu),
            0b10000_001 => instruction::alu_num(&mut cpu, AluInstruction::ADD),
            0b10001_001 => instruction::alu_num(&mut cpu, AluInstruction::SUB),
            0b10010_001 => instruction::alu_num(&mut cpu, AluInstruction::NAN),
            0b10100_001 => instruction::alu_num(&mut cpu, AluInstruction::SHL),
            0b10101_001 => instruction::alu_num(&mut cpu, AluInstruction::SHR),
            0b10110_001 => instruction::alu_num(&mut cpu, AluInstruction::EQU),
            0b10111_001 => instruction::alu_num(&mut cpu, AluInstruction::GRE),
            0b10000_010 => instruction::alu_ram(&mut cpu, AluInstruction::ADD),
            0b10001_010 => instruction::alu_ram(&mut cpu, AluInstruction::SUB),
            0b10010_010 => instruction::alu_ram(&mut cpu, AluInstruction::NAN),
            0b10100_010 => instruction::alu_ram(&mut cpu, AluInstruction::SHL),
            0b10101_010 => instruction::alu_ram(&mut cpu, AluInstruction::SHR),
            0b10110_010 => instruction::alu_ram(&mut cpu, AluInstruction::EQU),
            0b10111_010 => instruction::alu_ram(&mut cpu, AluInstruction::GRE),
            _ => instruction::noi(&mut cpu),
        }

        cpu.ic += 0x1;
        if cpu.ic.0 == 0x10 {
            cpu.ic = Wrapping(0x00);
        }

        step += 1;
    }
}

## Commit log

2022-10-17 comp: Allow for values to be in base 10
    I got tired of oly using hex values :)
2022-10-18 comp: Compiler was technically and assembler
2025-09-16 Add KiCAD files and instructions manual
    [alu.kicad_sch, bill-of-materials.csv, clk.kicad_sch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]
2025-09-17 kicad: compact design
    [SC08v2.kicad_pcb, SC08v2.kicad_sch, alu.kicad_sch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]
2025-09-18 kicad: finalize sketch
    [SC08v2.kicad_pcb, SC08v2.kicad_sch, alu.kicad_sch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]
2025-09-18 Add eeprom-flasher KiCAD files
    [SC08v2.kicad_pcb, SC08v2.kicad_sch, alu.kicad_sch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]
2026-07-10 Improve and fix docs
    [SC08v2.kicad_sch, alu.kicad_sch, bill-of-materials.csv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]
2026-07-22 Improve docs and schemas
    [SC08v2.kicad_pcb, SC08v2.kicad_sch, ic.kicad_sch]
